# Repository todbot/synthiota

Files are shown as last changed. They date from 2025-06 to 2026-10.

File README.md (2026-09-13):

# synthiota

Pico/Pico2-based board for playing with synthesizers in CircuitPython.

https://github.com/user-attachments/assets/1fe45b23-2a2a-41f4-9afe-203840c703e8

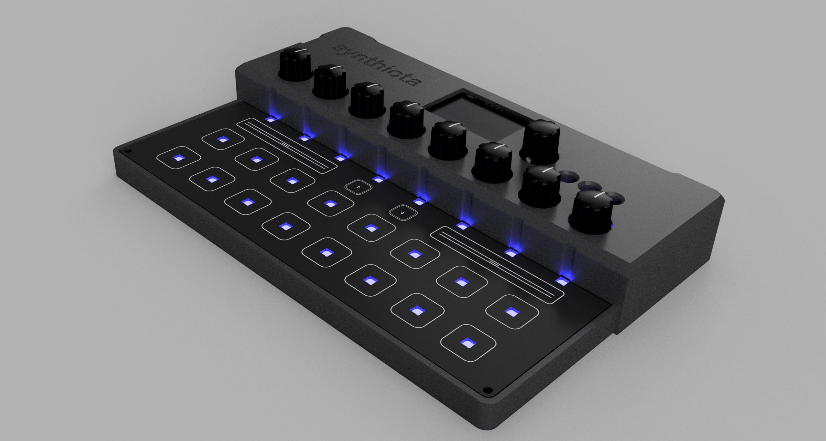
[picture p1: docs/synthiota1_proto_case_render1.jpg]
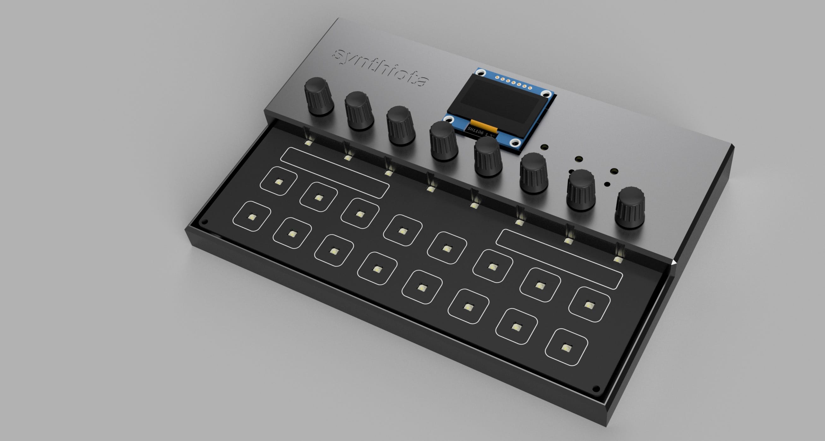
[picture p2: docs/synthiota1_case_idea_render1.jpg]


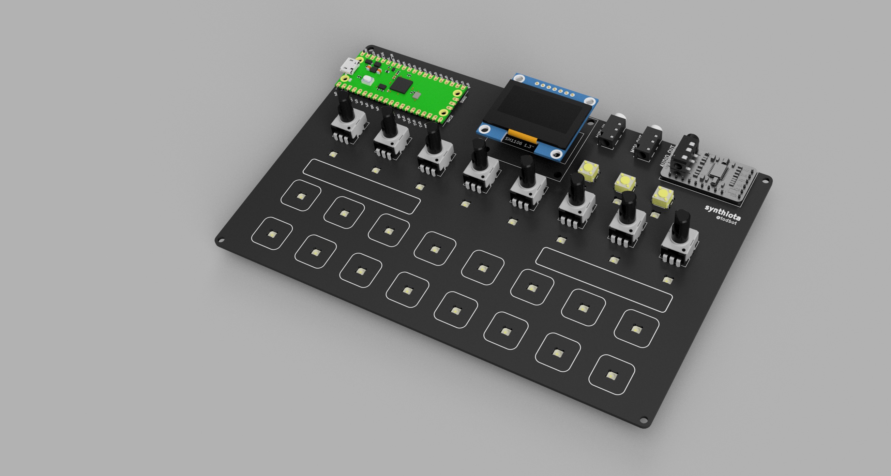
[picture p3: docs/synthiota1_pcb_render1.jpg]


## Video demos:

- "tbish" TB-303 like synth, demo2: https://youtu.be/MjE2wdevc3M
- "tbish" TB-303 like synth, demo1: https://youtu.be/O4a5pk78DVM

# Assembling

The PCBAs come with all SMD parts assembled. The components you will need to supply:

- 1 x Raspberry Pi Pico 2
- 1 x [PCM5102 I2S Stereo DAC](https://amzn.to/4nX4xkD)
- 1 x [SH1106 128x64 1.3" SPI OLED](https://amzn.to/4oUlOeM) 
- 2 x [PJ320A 3.5mm stereo jack](https://amzn.to/4i5F33d)
- 8 x [RK09K 10k vertical potentiometer](https://amzn.to/47XbwEk) (or similar)
- 1 x [EC11 rotary encoder](https://amzn.to/4o1vSSW)

You will also need some headers and header sockets to attach the modules to the PCB.
If using the [enclosure](./enclosure), the top part expects the header arrangement to be:

- Pico: 
  - Standard header pins on Pico  (Pico H sold w/ these pins soldered)
  - [Short socket headers](https://www.adafruit.com/product/5585) for Pico on synthiota board
- OLED display:
  - Standard header pins on OLED display  (usually sold w/ these pins soldered)
  - [Short socket headers](https://www.adafruit.com/product/5585) for OLED display on synthiota board
- PCM5102 I2S DAC
  - Standard header pins on PCM5102 I2S DAC board (usually sold w/ these pins soldered)
  - I2S DAC w/ header pins is soldered directly to the synthiota board, no socket

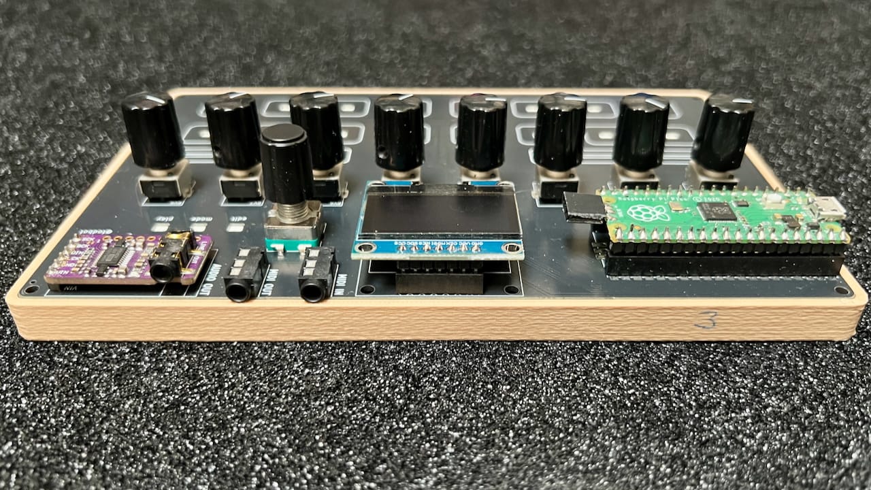
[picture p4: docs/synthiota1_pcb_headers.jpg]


(most links are Amazon affiliate links)

# Pico pins used

CircuitPython naming. See `hwtest/synth_setup_synthiota.py` for how they're used.

Encoder 

* `board.GP28`  - encoder B pin
* `board.GP27`  - encoder A pin

ADC input for pots

* `board.GP26`  - ADC input for pot knobs

I2S DAC 

* `board.GP22`  - I2S DAT pin to PCM5102 DAC
* `board.GP21`  - I2S LCK pin to PCM5102 DAC
* `board.GP20`  - I2S BCK pin to PCM5102 DAC

Encoder switch

* `board.GP19`  - encoder SW pin
 
NeoPixel LEDs
 
* `board.GP18`  - NeoPixel LEDs pin 
 
UART MIDI In/Out
 
* `board.GP17`  - UART RX pin to MIDI input
* `board.GP16`  - UART TX pin to MIDI output

SPI for display

* `board.GP13`  - SPI DC for SH1106 display
* `board.GP12`  - SPI RES for SH1106 display
* `board.GP11`  - SPI MOSI for SH1106 display
* `board.GP10`  - SPI SCK for SH1106 display

Pot mux select

* `board.GP9`   - SEL A pin to 4051 mux for pot knobs
* `board.GP8`   - SEL B pin to 4051 mux for pot knobs
* `board.GP7`   - SEL C pin to 4051 mux for pot knobs

I2C for MPR121 touch sensors

* `board.GP3`   - I2C SCL to MPR121 touch sensors
* `board.GP2`   - I2C SDA to MPR121 touch sensors

Free pins: GP0,GP1, GP4,GP5,GP6, GP14,GP15. Feel free to use for other purposes. 

# Schematics

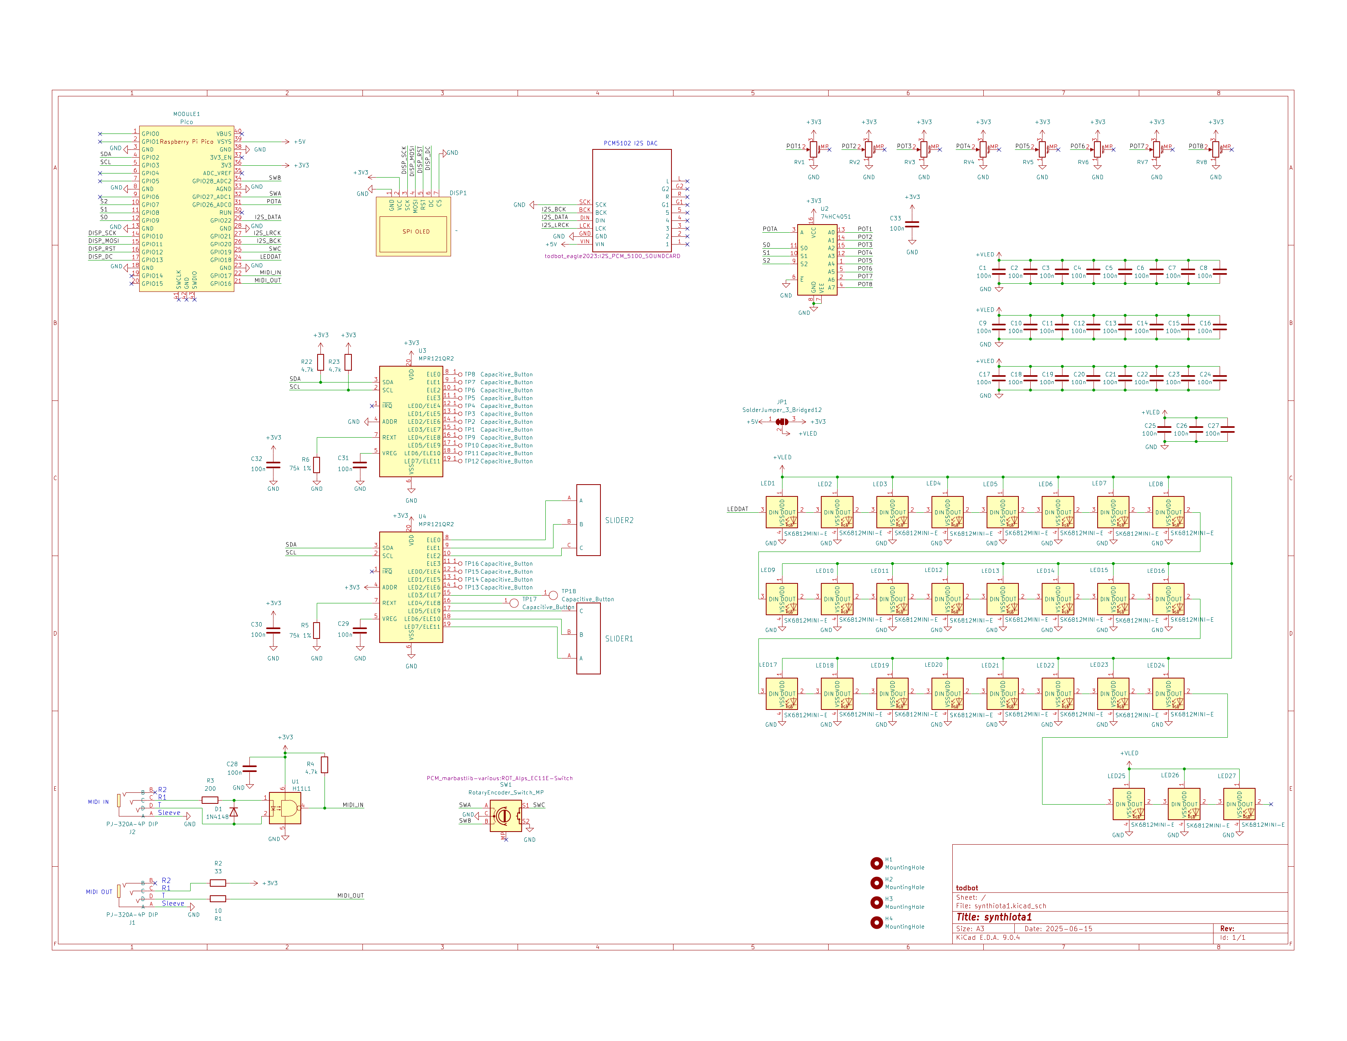
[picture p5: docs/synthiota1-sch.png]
[](./schematics/synthiota1/synthiota1-sch.pdf)

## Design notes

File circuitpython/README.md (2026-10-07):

To install needed third-party libraries, see "requirements.txt".
You can use "circup" to install them with `circup install -r requirements.txt`

For actual applications, see the directories.

- `polysynth/`  - subtractive polysynth on synthtools' SubtractiveSynth
- `wavesynth/`  - wavetable polysynth on synthtools' WavetableSynth
- `tbish/`      - TB-303 inspired mono bass synth
- `tbish2/`     - tbish on synthtools' BasslineSynth
- `synthtest/`  - earlier synth playground

`polysynth/` and `wavesynth/` are ported from the pico_test_synth repo
and run on the `relic_synthiota` hardware library (vendored in `lib/`,
from github.com/relic-se/CircuitPython_Synthiota). Each app folder has
its own README with the control map and copy-to-device steps.

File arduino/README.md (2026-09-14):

# synthiota Arduino sketches

Arduino sketches for the synthiota1 board (RP2040/RP2350), 
built with the [earlephilhower rp2040 core][rp2040-core] and `arduino-cli`.

[rp2040-core]: https://github.com/earlephilhower/arduino-pico

## Sketches

- **hwtest/hwtest1** -- board basic test: I2C scan, dual MPR121
  touch with NeoPixel feedback, 8-pot mux, rotary encoder + switch,
  and a SH1106 SPI OLED status page. See
  `circuitpython/hwtest/synth_setup_synthiota.py` for the pin map this
  is based on.
  
- **hwtest/hwtest2** -- simple monophonic MIDI synth using
  [M16](https://github.com/algomusic/M16), driving the PCM5102 I2S DAC. <br>
  (saw oscillator, fixed lowpass, AR envelope, TRS + USB MIDI)
  
- **hwtest/hwtest3** -- simple monophonic MIDI synth using 
  [Mozzi](https://sensorium.github.io/Mozzi/), similar to hwtest2. <br>
   (saw oscillator, fixed lowpass, AR envelope, TRS + USB MIDI)

## sketch.yaml profiles

Each sketch has a [`sketch.yaml`][sketch-yaml] pinning the exact
platform and library versions it was built against, as `pico` and
`pico2` profiles (`default_profile: pico2`). Profile builds are
self-contained -- `arduino-cli` downloads the pinned platform/library
versions into an isolated store on first use, independent of whatever
is installed globally -- so no separate `core install`/`lib install`
step is needed for these sketches.

Note the Arduino IDE does not read `sketch.yaml`; it only applies to
`arduino-cli` builds. Building from the IDE instead, just open the
`.ino` and pick the board from Tools > Board as usual (see "USB MIDI"
below for hwtest2's extra board option).

[sketch-yaml]: https://arduino.github.io/arduino-cli/latest/sketch-project-file/

## Board FQBNs

| Board | FQBN |
|---|---|
| Raspberry Pi Pico | `rp2040:rp2040:rpipico:usbstack=tinyusb`  |
| Raspberry Pi Pico 2 | `rp2040:rp2040:rpipico2:usbstack=tinyusb` |

## USB Serial and USB MIDI 

Sketches use USB via `Adafruit_TinyUSB` and need the board's
USB Stack set to **Adafruit TinyUSB** instead of the default Pico SDK
stack. If you're using `arduino-cli`, the sketch's `sketch.yaml` profiles
already bake this in, so use  `--profile pico2` or `--profile pico`. 

## Build and upload

From inside a sketch directory (e.g. `arduino/hwtest/hwtest1`):

```sh
# Pico
arduino-cli compile --profile pico .
arduino-cli upload -p /dev/ttyACM0 --profile pico .

# Pico 2 (the default profile)
arduino-cli compile --profile pico2 .
arduino-cli upload -p /dev/ttyACM0 --profile pico2 .

# serial monitor
arduino-cli monitor -p /dev/ttyACM0
```

Adjust `/dev/ttyACM0` to match the board's actual serial port (find it
with `arduino-cli board list`).

To (re)generate a sketch's `sketch.yaml` profiles rather than
hand-tracking library versions, use `arduino-cli`'s `--dump-profile`:

```sh
arduino-cli compile --fqbn rp2040:rp2040:rpipico2 --dump-profile .
```

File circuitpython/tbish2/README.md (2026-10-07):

# tbish2 for synthiota

A TB-303 inspired monophonic bass synth for Synthiota, on `synthtools`'
`BasslineSynth` and `StepSequencer`. The synth engine comes from
[pico_test_synth](https://github.com/todbot/pico_test_synth)'s `tbish2`;
the controls are this repo's [`tbish/`](../tbish/), which is left as is.

Compared to `tbish/`, the library synth adds:

- accent raises resonance (`accent_q`) and cutoff (`accent_cutoff`),
  not just level, and consecutive accents stack
- a real `slide_time`, and slides that TIE: the pitch glides and the
  envelopes carry on, like the original
- a 24 dB/oct filter, drive (RP2350 only) and delay, all as patch fields

## Modes

The encoder steps through three modes, shown bottom right of the screen
and on the mode LEDs:

- **play** .. the 8 pots are the main 303 knobs: cutoff, envmod, resQ,
  decay, accent, wave, drive, delaymix
- **edit** .. the 8 pots set 8 step notes; the screen shows those 8
  steps, with `A` for accent and `S` for slide over each
- **more** .. the 8 pots are the rest of the synth: ampdec, amplevel,
  acctcut, acctQ, slide, drvamt, dtime, dlyfeed

Patterns are 16 steps, shown 8 at a time: `1-8` or `9-16` top right.
Edit mode works on one half, picked with the left slider's middle;
play and more show whichever half is playing.

In play and more, all 8 pots are live and the screen shows the pair
(1-2, 3-4, 5-6, 7-8) of the pot turned last. The pots are scaled
takeover: a turn always moves its parameter, scaled so knob and value
converge without a jump.

## Controls

- encoder turn ............ next / previous mode
- encoder push ............ play / pause; pausing saves to `/tbish2.json`
- step pads, playing ...... transpose the pattern (pad 9 is home)
- step pads, stopped ...... play the synth
- step pads, edit mode .... bottom row: step note <-> rest;
                            top row: normal -> accent -> slide -> both
- up / down buttons ....... transpose up / down an octave
- right slider, left end .. previous pattern
- right slider, right end . next pattern
- hold either right slider end, turn encoder .. scroll patterns
- left slider, middle ..... edit steps 1-8 / 9-16
- hold left slider left end, turn encoder ... bpm
- hold left slider right end, turn encoder .. steps per beat
- pot LEDs ................ current step, if on the shown half
- step LEDs ............... held pads; in edit mode, the pattern
                            (white = note, red = accent, blue = slide)

There's no MIDI in or out yet.

## Patterns

The first five are famous 303 lines, transcribed at
[JonDent's famous 303 bassline patterns](https://djjondent.blogspot.com/2020/04/famous-303-bassline-patterns-page-1.html).
The original BPM is in a comment on each; tbish2 doesn't change tempo
per pattern.

1. Josh Wink - Higher State of Consciousness (134 BPM)
2. Phuture - Acid Tracks (~120 BPM; notes only, no accents or slides)
3. Fast Eddie - Acid Thunder (x0xb0x transcription)
4. DJ Tim & Misjah - Access (134 BPM)
5. New Order - Confusion, Pump Panel Reconstruction (134 BPM)

The rest are tbish's own 8-step patterns, played twice. Patterns saved
in `/tbish2.json` by an 8-step version are ignored, since they no longer
fit; the knobs and bpm still load.

## Running it

From `circuitpython/`:

    circup install -r requirements.txt

Copy to the CIRCUITPY root: `code.py`, `tbish2_ui.py` and `boot.py` from
this folder, plus `lib/relic_synthiota.py`.

`boot.py` makes the filesystem writable from the board's side, so pause
can save the knobs, bpm and patterns. Without it saving fails with a
printed note, and everything else works.

Needs a CircuitPython build with `audiofilters` and `audiodelays` for
the 24 dB filter, drive and delay. Without them it runs on the voice's
own 12 dB filter and says so at boot.

## Notes

- `decay` is the FILTER fall time in seconds; the amp's decay is its own
  knob (`ampdec`) and wants to stay longer, or the sweep is masked. A run
  of slides is one held note on one amp envelope, so `ampdec` also has to
  outlast the whole run, or its later notes fade to nothing.
- `drive` is the distortion's dry/wet mix, as on tbish; how hard it
  distorts is `drvamt` on the more page. RP2350 only.
- `dtime` is milliseconds.
- Audio runs at 44100 Hz, mono: in stereo the delay's buffer is too big
  to allocate. If it glitches, set SAMPLE_RATE to 22050.
- 303 research links: see [`../tbish/README.md`](../tbish/README.md).

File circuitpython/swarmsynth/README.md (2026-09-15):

# swarmsynth for synthiota

A Dewanatron Swarmatron-style drone machine for Synthiota, on
`synthtools`' `SwarmSynth`: eight oscillators on one pitch, fanned apart
by a single "swarm" control and each drifting independently.

The real instrument is monophonic, played from a pitch ribbon, with a
second ribbon and a knob pulling the oscillators from a few cents apart
out to a wide chord of equidistant pitches. This is that, on the pads:
the **bottom row** is eight scale degrees, the **top row** re-aims the
drone by octaves and fifths, and the **right slider** is the span
ribbon. Working the pitch and the span together -- Dewanatron's "taffy
pulling" -- is what the instrument is for.

The 8 pots are one page of 8 parameters, paired on screen so each pair
is one idea. All 8 are live; the screen shows one pair large -- turning
any pot snaps it to that pot's pair (1-2, 3-4, 5-6, 7-8), each param as
`P<n> name` over a big value. The 8 pot LEDs show all 8 values.

The pots are scaled takeover: turning one always moves its parameter,
scaled so the knob and the value converge without a jump, so a nudged
pot never snaps a drone.

## Controls

- bottom pads (1-8) .. the 8 scale degrees (natural minor), one note each
- top pads (9-16) .... transpose the drone: -24 -12 -7 0 +7 +12 +19 +24
                       semitones (pad 12 is home)
- 8 pots ............. 8 params at once; screen shows the last-turned pair
- up / down buttons .. octave down / up (C1 .. C5)
- encoder turn ....... octave down / up (same as the buttons)
- encoder press ...... latch on / off -- the drone keeps sounding after
                       you let go, so both hands are free for the knobs
- left slider ........ nudge filter cutoff (while touched)
- right slider ....... the span ribbon: swarm spread (while touched)
- pot LEDs .......... all 8 param values
- step LEDs ......... held / latched degree, and the chosen transposition
- play LED .......... lit while latched

Bottom-row pads are last-note priority, so rolling a finger across them
glides the drone instead of cutting it. Both sliders move the parameter
itself, so the screen, the pot LED and the pot's takeover all follow
the ribbon.

Page SWARM:  spred drift count wave  freq reso glide rel

- `spred` .. the outermost oscillator's offset, in octaves. 0 is unison,
             0.01 is +/-12 cents, 0.4 is an equidistant cluster spread
             over most of an octave either way.
- `drift` .. depth of each oscillator's slow independent wander. 0 is
             perfect digital tuning, which sounds like a chorus pedal;
             a few thousandths is what makes the swarm breathe.
- `count` .. oscillators per note, 1 to 8.
- `wave` ... SAW SQU TRI SIN ASAW ATRI ASQU SSQU.
- `glide` .. portamento, the pitch ribbon's glissando.

## MIDI

Responds to NOTE ON/OFF on any channel (monophonic), CC 1 (swarm
spread), CC 74 (filter cutoff), CC 120/123 (all notes off). Sends NOTE
ON/OFF for every pitch the pads trigger, on USB and UART -- including
the off that a pitch change implies, since the synth is mono.

A note arriving over MIDI is played as sent, so the top row has nothing
to re-aim while it sounds: the transposition you pick applies to the
next pad press.

## Running it

From `circuitpython/`:

    circup install -r requirements.txt

That installs `synthtools` and the other third-party libraries, plus
the local `lib/` modules (`relic_synthiota.py`, `synthiota_potpage_ui.py`).

Copy to the CIRCUITPY root: the contents of this folder, plus
`lib/synthtools/` and the `lib/*.py` modules.

`relic_synthiota.py` originates at
github.com/relic-se/CircuitPython_Synthiota

## Notes

- `wave` and `count` apply at the NEXT note-on: the waveform is baked
  into each `synthio.Note` and the count decides how many Notes a press
  builds. Re-press a pad to hear either one change. `spred` and `drift`
  are each one write into a shared block and move a held drone live,
  which is the whole point of the engine.
- Turning `count` down under a held drone re-tunes it: the fan
  coefficients are shared, so the sounding oscillators re-space to the
  new count even though they keep their number.
- `rel` stops at 2.0s on purpose. Mono at 8 oscillators is 8 Notes,
  16 while a steal overlaps the releasing swarm with the new one,
  against synthio's 24. A longer tail plus a fast roll across pads
  stacks a third releasing swarm and the oldest gets dropped.
- `SwarmSynth.FILT_F_MAX` is set from `sample_rate * 0.45` before the
  synth is constructed: the Nyquist clamp is baked into the block graph
  at build time.
- The mixer voice runs at 0.8 because each Note is amplitude
  `velocity / 127 / swarm_count`: detuned oscillators beat, so their
  peaks do periodically line up, and the level is made back up here.
- Audio runs at 44100 Hz. If it glitches, set SAMPLE_RATE to 22050.

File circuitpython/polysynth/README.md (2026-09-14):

# polysynth for synthiota

A playable two-oscillator subtractive polysynth for Synthiota, on
`synthtools`' `SubtractiveSynth`. Ported from 
[pico_test_synth](https://github.com/todbot/pico_test_synth)'s 
`synthtools_polysynth`.

The 16 step pads are a chromatic keyboard. The 8 pots edit 8 parameters
at once; the encoder turns pages (16 parameters over 2 pages, OSC/AMP
and FILT/MOD). All 8 pots on a page are live, but the screen shows one
pair large -- turning any pot snaps it to that pot's pair (1-2, 3-4,
5-6, 7-8), each param as `P<n> name` over a big value. The 8 pot LEDs
show all 8 values on the page. USB and TRS MIDI both play the synth;
pad presses echo out both.

The pots are scaled takeover: turning one always moves its parameter,
scaled so the knob and the value converge without a jump, so a page
turn or a nudged pot never snaps a sound.

## Controls

- step pads .......... chromatic keyboard (16 notes)
- 8 pots ............. 8 params at once; screen shows the last-turned pair
- encoder turn ....... previous / next page
- up / down buttons .. octave down / up (C1 .. C5)
- left slider ........ nudge filter cutoff (while touched)
- right slider ....... vibrato depth (while touched)
- pot LEDs .......... all 8 param values on this page
- step LEDs ......... currently held notes

## MIDI

Responds to NOTE ON/OFF on any channel, CC 1 (vibrato depth), CC 74
(filter cutoff), CC 120/123 (all notes off). Sends NOTE ON/OFF for pad
presses on USB and UART.

## Running it

From `circuitpython/`:

    circup install -r requirements.txt

That installs `synthtools` and the other third-party libraries, plus
the local `lib/` modules (`relic_synthiota.py`, `synthiota_potpage_ui.py`).

Copy to the CIRCUITPY root: the contents of this folder, plus
`lib/synthtools/` and the `lib/*.py` modules.

`relic_synthiota.py` originates at
github.com/relic-se/CircuitPython_Synthiota

## Notes

- `SubtractiveSynth.FILT_F_MAX` is set from `sample_rate * 0.45` before
  the synth is constructed: the Nyquist clamp is baked into the block
  graph at build time.
- Audio runs at 44100 Hz. If it glitches, set SAMPLE_RATE to 22050.
- `detune` below 1.0005 snaps to exactly 1.0, which is the single-
  oscillator path (one Note per key). Any real detune spends two Notes
  per key.

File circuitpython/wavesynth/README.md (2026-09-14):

# wavesynth for synthiota

A wavetable polysynth for Synthiota, on `synthtools`' `WavetableSynth`.
Ported from pico_test_synth's `wavesynth`.

`wpos` moves within the loaded wavetable and morphs sounding notes
live; `wsel` picks which `.WAV` in `wavetables/`. Two LFOs: `lamt` /
`lrate` over the filter cutoff, and `wlfo` / `wrate` sweeping `wpos` up
toward `wlfo` (a ceiling at or below `wpos` means no sweep).

The 16 step pads are an 8x2 **scale keyboard** (`lib/harmony.py`): the
bottom row is the 8 scale degrees, one note each; the top row plays a
diatonic chord on the last bottom pad pressed. Scale and key are on the
KEY/MOD page.

The 8 pots edit 8 parameters at once and the encoder turns pages (24
parameters over 3 pages: WAVE, ENV/FILT, KEY/MOD). All 8 pots on a page
are live, but the screen shows one pair large -- turning any pot snaps
it to that pot's pair (1-2, 3-4, 5-6, 7-8), each param as `P<n> name`
over a big value. The 8 pot LEDs show all 8 values on the page.

The pots are scaled takeover: turning one always moves its parameter,
scaled so the knob and the value converge without a jump, so a page
turn or a patch load never snaps a sound.

Nine patches are defined in code (`default_patches()`); there is no
disk save.

## Controls

- bottom pads (1-8) ...... the 8 scale degrees, one note each
- top pads (9-16) ........ chord on the last bottom pad: root, oct, 5th,
                           triad, 7th, 9th, sus, spread (all diatonic)
- 8 pots ................. 8 params at once; screen shows the last-turned pair
- encoder turn ........... previous / next page
- encoder HOLD + bottom pad  load patch 1..8
- up / down buttons ...... octave down / up
- left slider ............ nudge filter cutoff (while touched)
- right slider ........... wavetable position (while touched)
- pot LEDs .............. all 8 param values on this page
- step LEDs ............. currently held pads

Page WAVE:    freq reso wpos wsel wlfo wrate atk rel
Page ENV/FILT: fatk frel famt ftype lamt lrate vdep vol
Page KEY/MOD: scale key wshp w1x wvel vrate pamt ptime
  (wshp/w1x/wvel = wave-LFO shape / one-shot / velocity depth)

## MIDI

Responds to NOTE ON/OFF on any channel (played chromatically, not
snapped to the scale), CC 1 (wavetable position), CC 74 (filter
cutoff), CC 120/123 (all notes off). Sends NOTE ON/OFF for every note a
pad triggers, on USB and UART.

## Running it

From `circuitpython/`:

    circup install -r requirements.txt

That installs `synthtools` and the other third-party libraries, plus
the local `lib/` modules (`relic_synthiota.py`, `synthiota_potpage_ui.py`,
`harmony.py`).

Copy to the CIRCUITPY root: the contents of this folder including
`wavetables/`, plus `lib/synthtools/` and the `lib/*.py` modules.
Then run `dot_clean -m /Volumes/CIRCUITPY`.

`harmony.py` (scales + chords) is standalone for now, headed for
`synthtools.harmony`.

`relic_synthiota.py` originates at
github.com/relic-se/CircuitPython_Synthiota.

## Notes

- Audio runs at 44100 Hz. Set `SAMPLE_RATE` to 22050 if it glitches.
- `WavetableSynth.FILT_F_MAX` is set from `sample_rate * 0.45` before
  the synth is constructed (Nyquist clamp, baked in at build time).
- `wpos` and `wlfo` are re-ranged whenever `wsel` loads a different
  file: the wavetables here hold 64 waves each and a fixed ceiling would
  hide most of every table.
- The wave LFO only advances when `synth.update()` runs; the main loop
  calls it every pass, a cheap no-op while `wlfo <= wpos`.
- macOS drops `._`-prefixed AppleDouble files into `wavetables/` on a
  FAT drive; `wave_files()` skips them, but `dot_clean -m /Volumes/CIRCUITPY`
  after copying is still worth it.

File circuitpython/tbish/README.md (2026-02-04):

# TBish synth

A TB-303 inspired monophonic bass synth.

Video demo on synthiota1: https://www.youtube.com/watch?v=O4a5pk78DVM

Video demo of pico_test_synth running tbish: https://www.youtube.com/watch?v=1AflpXbEIno

Current code in here is a technology demo. 
There's no way to edit patterns or play it via MIDI. 

notes: 

- [Analysis of Diode Ladder Filter in TB303](https://www.timstinchcombe.co.uk/index.php?pge=diode)
- [Devilfish mods of TB303, increasing range of CutOff & EnvMod pots](https://www.firstpr.com.au/rwi/dfish/303-mods/)
- [Investigating unique aspects of the 303 sound, particular the filter envelope](https://www.firstpr.com.au/rwi/dfish/303-unique.html)
- [kvr forum discussion of 303 ladder filter, with commens by u-he](https://www.kvraudio.com/forum/viewtopic.php?t=346155)
- [modwigger forum on 303 circuit modeling](https://modwiggler.com/forum/viewtopic.php?t=289244)
- [TeeBeeFilter.h - C model of 303/Moog ladder filter](https://github.com/RobinSchmidt/Open303/blob/main/Source/DSPCode/rosic_TeeBeeFilter.h)
- [x0xb0x filter block diagram](https://www.ladyada.net/wiki/x0x/voltagecontrolledfilter)
- [Emulate a 303 with Ableton's Operator plugin](https://beatproduction.net/how-to-emulate-a-tb-303-with-abletons-operator/)
- [Reddit post of recreating 303 sound in Eurorack](https://www.reddit.com/r/modular/comments/bvoqff/making_a_eurorack_tb303/)

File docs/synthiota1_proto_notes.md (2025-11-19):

# Synthiota1 Proto 15 Jun 2025 Notes

## Overall

- All the parts of the board seem to work!

## PCB

- Sliders suck, they're too small
  - Can somewhat fix it in software by increasing the charge current, 
   `mpr121s[1]._write_register_byte(adafruit_mpr121.MPR121_CONFIG1, 0x20)  # default, 2*16uA charge current? `
   - solution: make sliders taller? ditch sliders entirely? 

- Layout too cramped vertically, towards the pot LED area

- Missing Play/Pause button? 
  - new 1 Sep 2025 version adds another touch button for this

## Software

- Maybe model after the Bass Station II

    - patch parameters:
      - osc1 octave
      - osc1 mod env depth
      - osc1 lfo depth
      - osc1 waveform
      - amp env attack
      - amp env release
      - amp env sustain
      - amp env decay
      
      - filt type
      - filt freq
      - filt resonance
      - filt env attack
      - filt env release
      - filt env sustain
      - filt env decay
      
      - delay
      - overdrive
      - reverb
      - detune

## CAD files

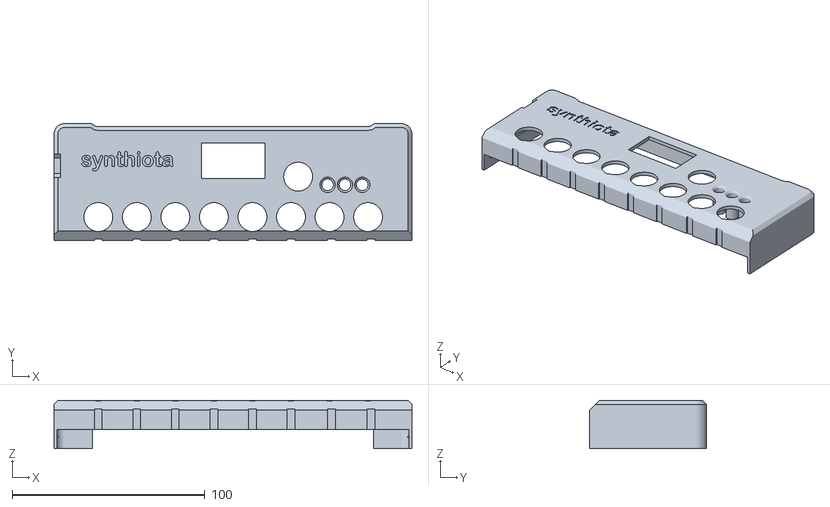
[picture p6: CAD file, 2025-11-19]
enclosure/synthiota_proto_case_top.stl
185.8 x 60.7 x 25.0

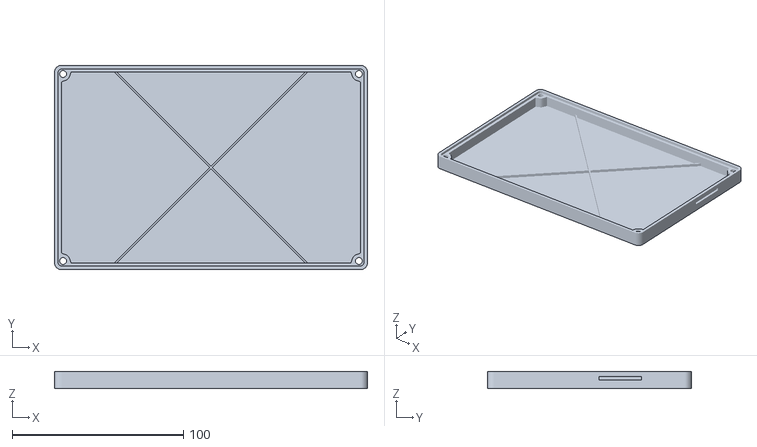
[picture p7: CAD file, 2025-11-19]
enclosure/synthiota_proto_case_bot.stl
182.8 x 119.3 x 10.00

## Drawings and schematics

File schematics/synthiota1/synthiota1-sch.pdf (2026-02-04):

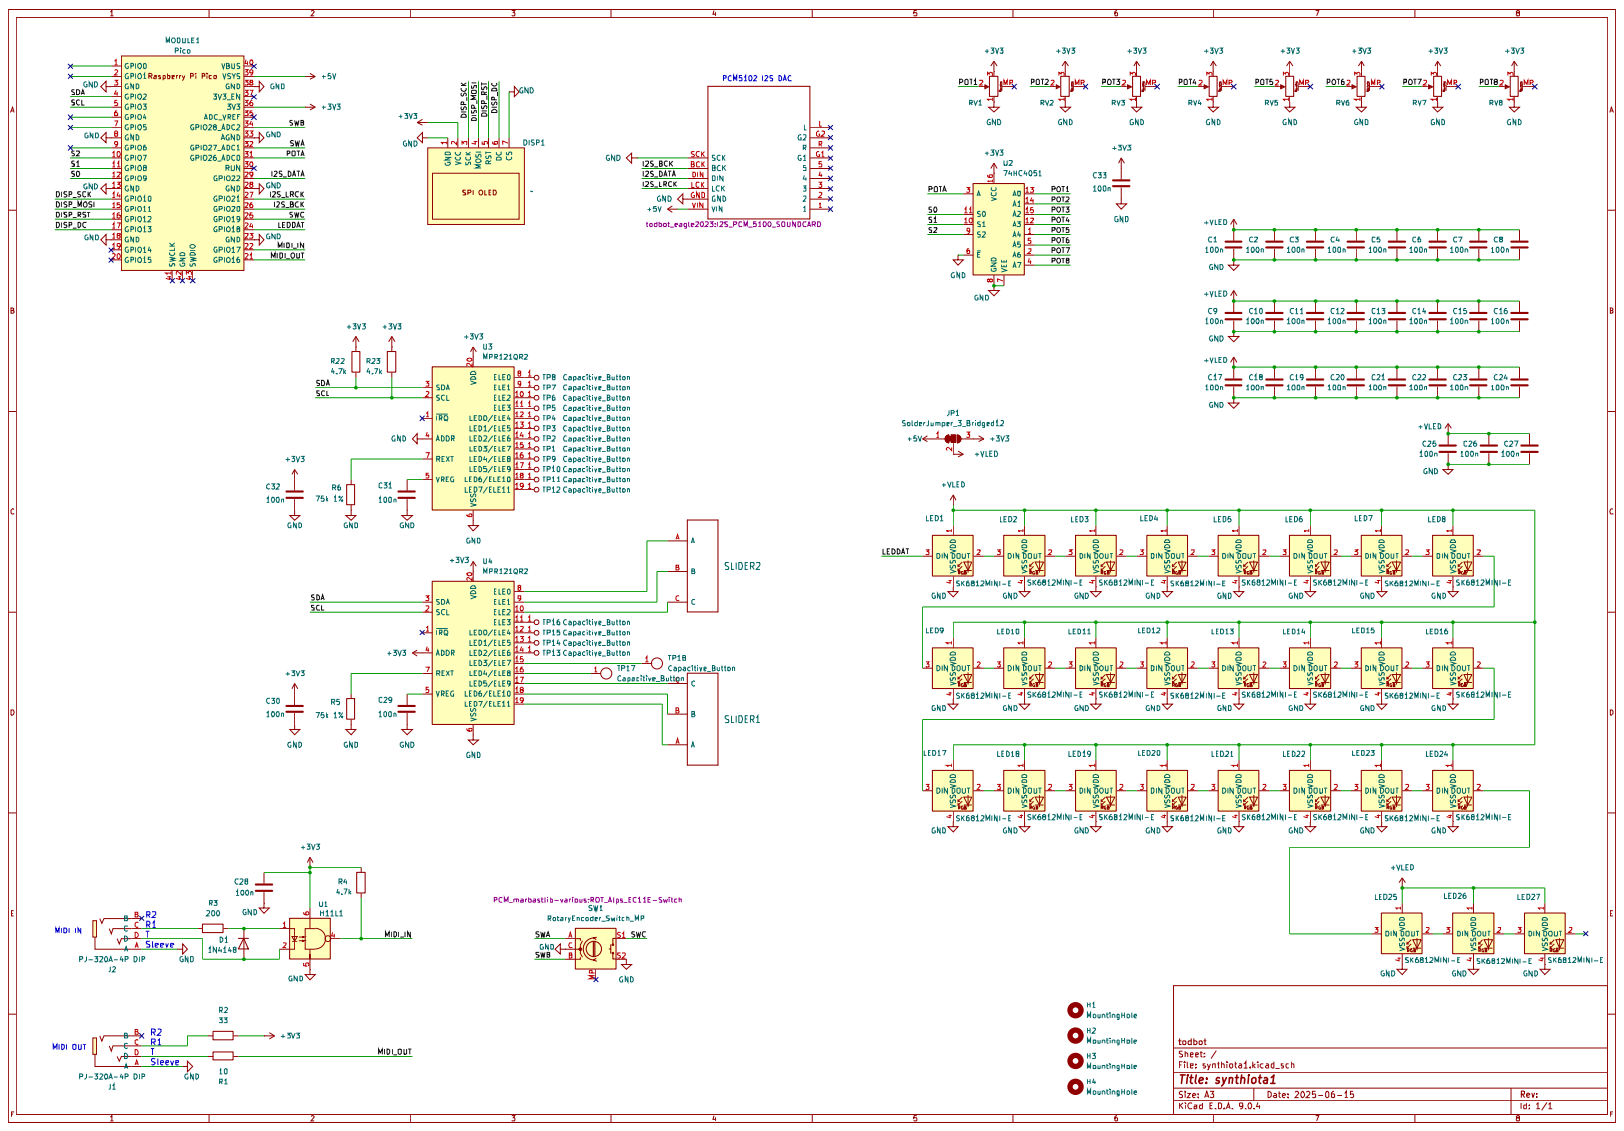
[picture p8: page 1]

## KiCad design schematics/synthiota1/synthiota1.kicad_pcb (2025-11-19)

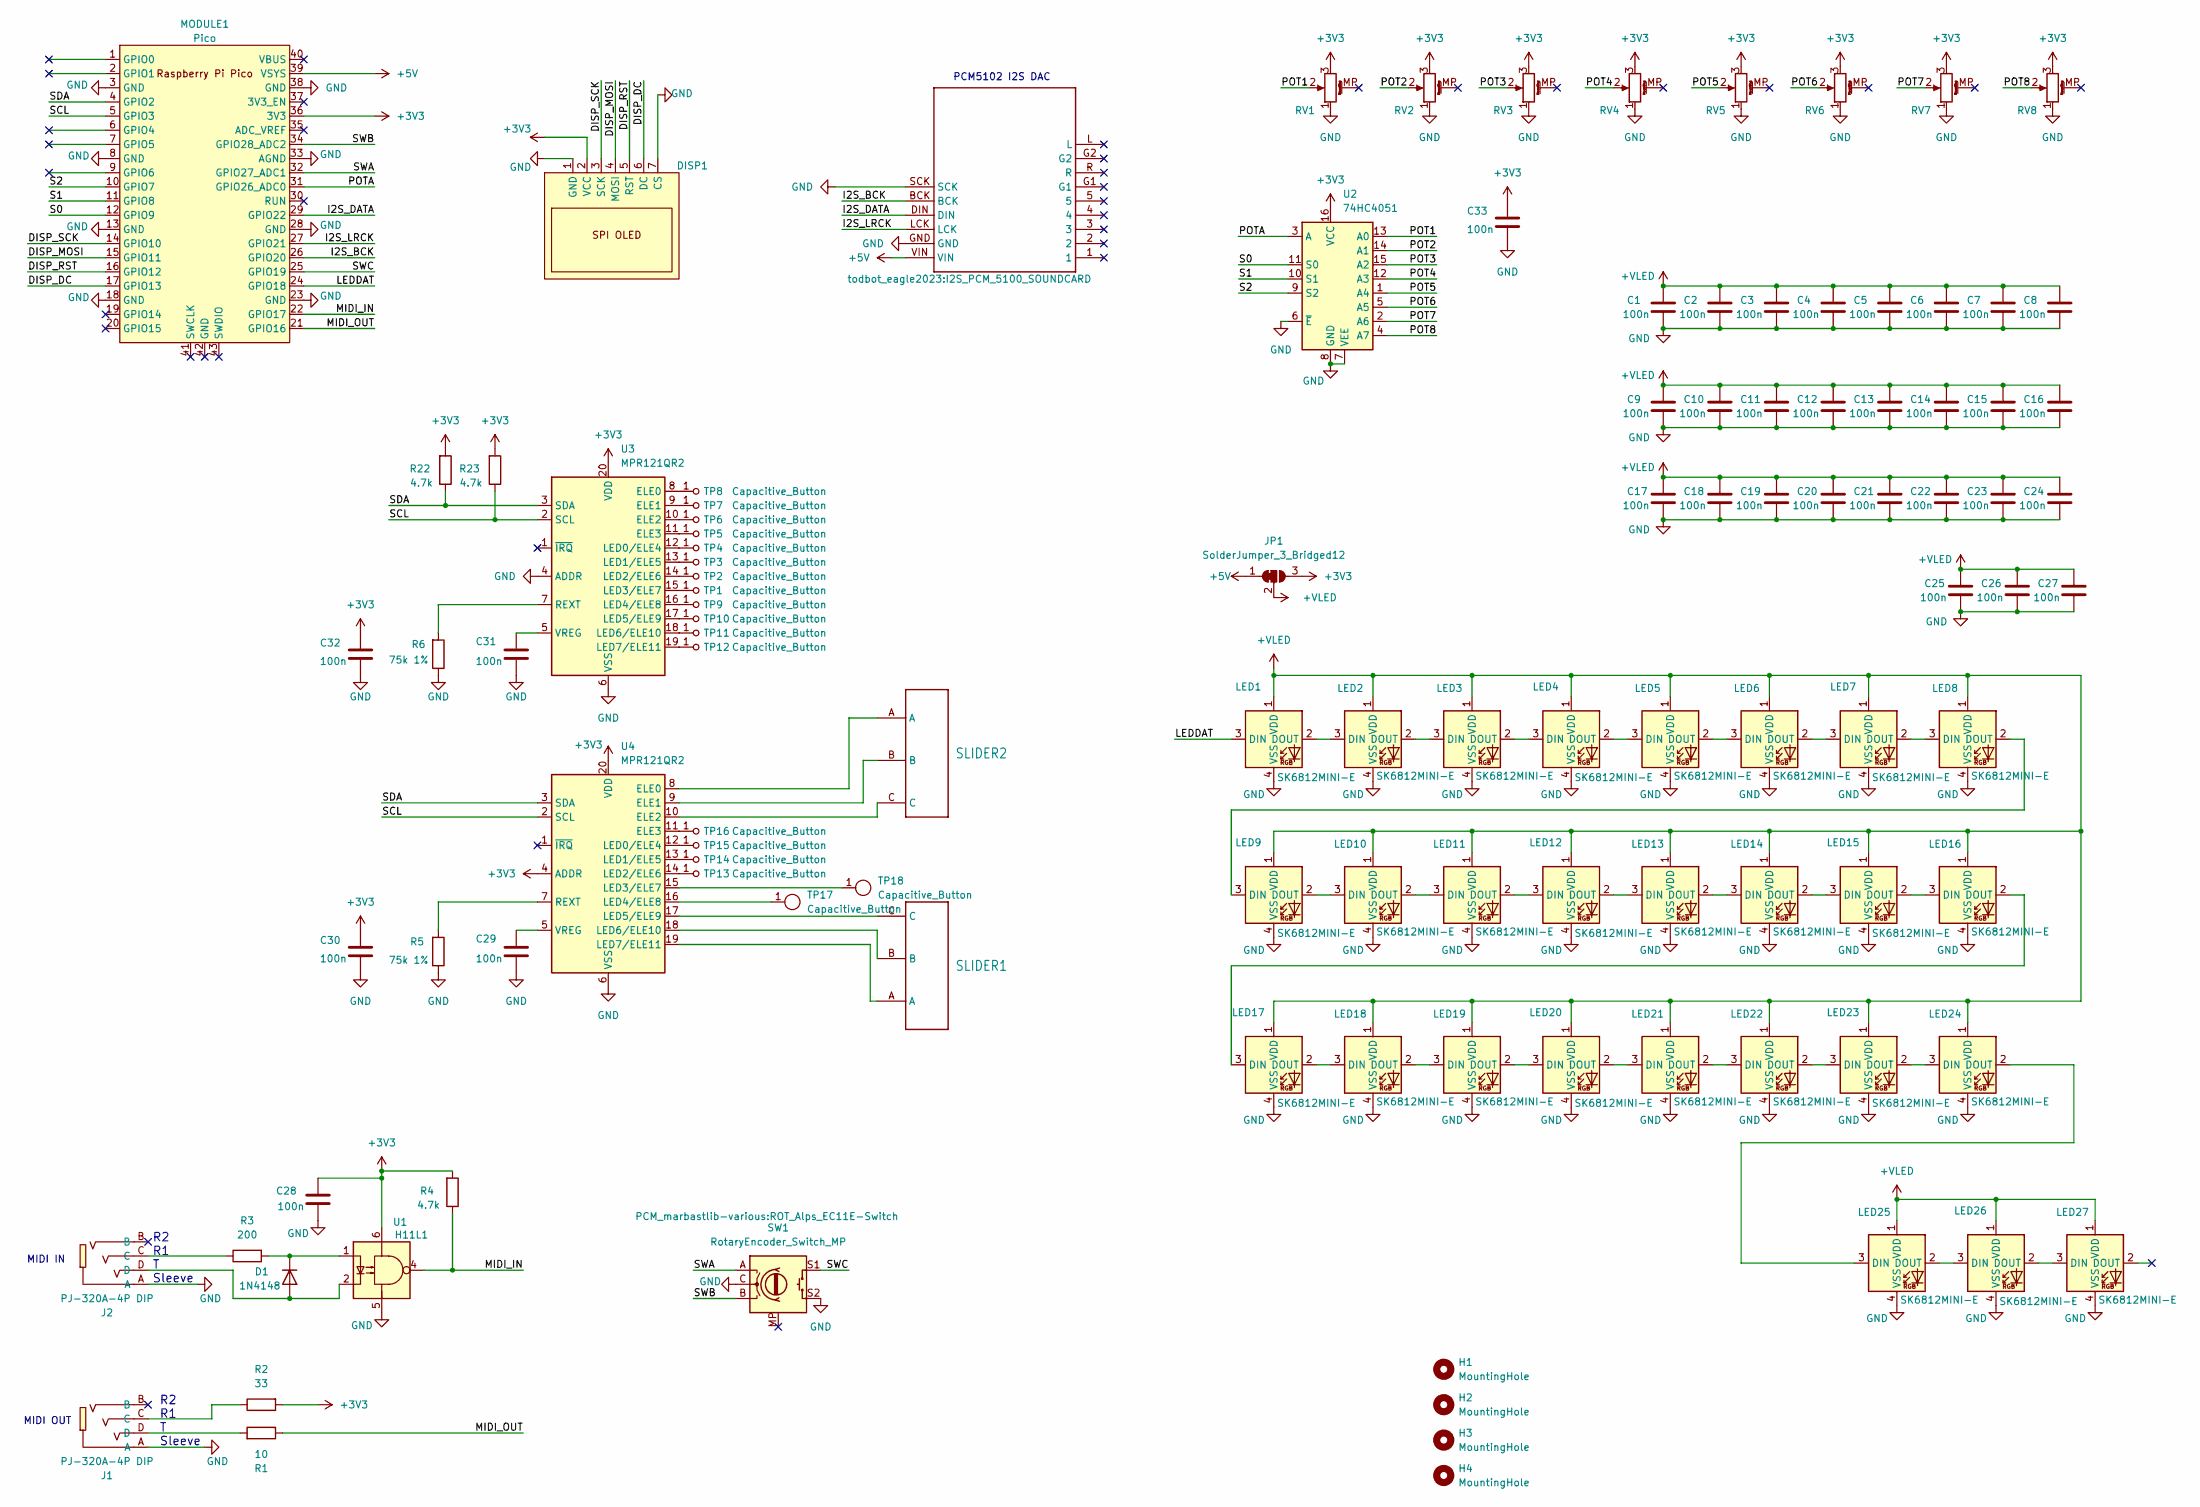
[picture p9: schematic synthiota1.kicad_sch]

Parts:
C1, C2, C3, C4, C5, C6, C7, C8, C9, C10, C11, C12, C13, C14, C15, C16, C17, C18, C19, C20, C21, C22, C23, C24, C25, C26, C27, C28, C29, C30, C31, C32, C33: 100n; C_0603_1608Metric; LCSC Part C1590
D1: 1N4148; D_SOD-123; LCSC Part C81598
DISP1: DISPLAY-OLED-128X64-1.3IN
H1, H2, H3, H4: MountingHole; MountingHole_2.7mm_M2.5
J1, J2: PJ-320A-4P DIP; AUDIO-TH_PJ-320A-4P-DIP; LCSC Part C18185602
JP1: SolderJumper_3_Bridged12; SolderJumper-3_P1.3mm_Bridged12_RoundedPad1.0x1.5mm
LED1, LED2, LED3, LED4, LED5, LED6, LED7, LED8, LED9, LED10, LED11, LED12, LED13, LED14, LED15, LED16, LED17, LED18, LED19, LED20, LED21, LED22, LED23, LED24, LED25, LED26, LED27: SK6812MINI-E; LED_6028R; LCSC Part C5149201
MODULE1: Pico; RPi_Pico_SMD_TH
MODULE2: I2S_PCM_5100_SOUNDCARD
R1: 10; R_0603_1608Metric; LCSC Part C22859
R2: 33; R_0603_1608Metric; LCSC Part C23140
R3: 200; R_0603_1608Metric; LCSC Part C8218
R4, R22, R23: 4.7k; R_0603_1608Metric; LCSC Part C23162
R5, R6: 75k 1%; R_0603_1608Metric; LCSC Part C23242
RV1, RV2, RV3, RV4, RV5, RV6, RV7, RV8: R_Potentiometer_MountingPin; Potentiometer_Alps_RK09K_Single_Vertical
SLIDER1, SLIDER2: TouchSlider3_50x8mm_ti
SW1: RotaryEncoder_Switch_MP; ROT_Alps_EC11E-Switch
TP1, TP2, TP3, TP4, TP5, TP6, TP7, TP8, TP9, TP10, TP11, TP12, TP13, TP14, TP15, TP16: Capacitive_Button; TOUCHPAD_KEY_0.5IN_LEDHOLE
TP17, TP18: Capacitive_Button; Pad-CapTouch-8mm-roundrect
U1: H11L1; SMD-6_L7.3-W6.5-P2.54-LS10.2-BL; LCSC C78589
U2: 74HC4051; SOIC-16_L9.9-W3.9-P1.27-LS6.0-BL; LCSC Part C2943297
U3, U4: MPR121QR2; UQFN-20_3x3mm_P0.4mm; LCSC Part C91322

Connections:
+3V3: C28.1, C30.1, C32.1, C33.1, DISP1.2 (VCC), JP1.3 (B), MODULE1.36 (3V3), R2.2, R4.2, R22.2, R23.2, RV1.3, RV2.3, RV3.3, RV4.3, RV5.3, RV6.3, RV7.3, RV8.3, U1.6, U2.16 (VCC), U3.20 (VDD), U4.4 (ADDR), U4.20 (VDD)
+5V: JP1.1 (A), MODULE1.39 (VSYS), MODULE2.VIN
+VLED: C1.1, C2.1, C3.1, C4.1, C5.1, C6.1, C7.1, C8.1, C9.1, C10.1, C11.1, C12.1, C13.1, C14.1, C15.1, C16.1, C17.1, C18.1, C19.1, C20.1, C21.1, C22.1, C23.1, C24.1, C25.1, C26.1, C27.1, JP1.2 (C), LED1.1 (VDD), LED2.1 (VDD), LED3.1 (VDD), LED4.1 (VDD), LED5.1 (VDD), LED6.1 (VDD), LED7.1 (VDD), LED8.1 (VDD), LED9.1 (VDD), LED10.1 (VDD), LED11.1 (VDD), LED12.1 (VDD), LED13.1 (VDD), LED14.1 (VDD), LED15.1 (VDD), LED16.1 (VDD), LED17.1 (VDD), LED18.1 (VDD), LED19.1 (VDD), LED20.1 (VDD), LED21.1 (VDD), LED22.1 (VDD), LED23.1 (VDD), LED24.1 (VDD), LED25.1 (VDD), LED26.1 (VDD), LED27.1 (VDD)
/DISP_DC: DISP1.6 (DC), MODULE1.17 (GPIO13)
/DISP_MOSI: DISP1.4 (MOSI), MODULE1.15 (GPIO11)
/DISP_RST: DISP1.5 (RST), MODULE1.16 (GPIO12)
/DISP_SCK: DISP1.3 (SCK), MODULE1.14 (GPIO10)
/I2S_BCK: MODULE1.26 (GPIO20), MODULE2.BCK
/I2S_DATA: MODULE1.29 (GPIO22), MODULE2.DIN
/I2S_LRCK: MODULE1.27 (GPIO21), MODULE2.LCK
/LEDDAT: LED1.3 (DIN), MODULE1.24 (GPIO18)
/MIDI_IN: MODULE1.22 (GPIO17), R4.1, U1.4
/MIDI_OUT: MODULE1.21 (GPIO16), R1.1
/POT1: RV1.2, U2.13 (A0)
/POT2: RV2.2, U2.14 (A1)
/POT3: RV3.2, U2.15 (A2)
/POT4: RV4.2, U2.12 (A3)
/POT5: RV5.2, U2.1 (A4)
/POT6: RV6.2, U2.5 (A5)
/POT7: RV7.2, U2.2 (A6)
/POT8: RV8.2, U2.4 (A7)
/POTA: MODULE1.31 (GPIO26_ADC0), U2.3 (A)
/S0: MODULE1.12 (GPIO9), U2.11 (S0)
/S1: MODULE1.11 (GPIO8), U2.10 (S1)
/S2: MODULE1.10 (GPIO7), U2.9 (S2)
/SCL: MODULE1.5 (GPIO3), R23.1, U3.2 (SCL), U4.2 (SCL)
/SDA: MODULE1.4 (GPIO2), R22.1, U3.3 (SDA), U4.3 (SDA)
/SWA: MODULE1.32 (GPIO27_ADC1), SW1.A
/SWB: MODULE1.34 (GPIO28_ADC2), SW1.B
/SWC: MODULE1.25 (GPIO19), SW1.S1
GND: C1.2, C2.2, C3.2, C4.2, C5.2, C6.2, C7.2, C8.2, C9.2, C10.2, C11.2, C12.2, C13.2, C14.2, C15.2, C16.2, C17.2, C18.2, C19.2, C20.2, C21.2, C22.2, C23.2, C24.2, C25.2, C26.2, C27.2, C28.2, C29.2, C30.2, C31.2, C32.2, C33.2, DISP1.1 (GND), DISP1.7 (CS), J1.A, J2.A, LED1.4 (VSS), LED2.4 (VSS), LED3.4 (VSS), LED4.4 (VSS), LED5.4 (VSS), LED6.4 (VSS), LED7.4 (VSS), LED8.4 (VSS), LED9.4 (VSS), LED10.4 (VSS), LED11.4 (VSS), LED12.4 (VSS), LED13.4 (VSS), LED14.4 (VSS), LED15.4 (VSS), LED16.4 (VSS), LED17.4 (VSS), LED18.4 (VSS), LED19.4 (VSS), LED20.4 (VSS), LED21.4 (VSS), LED22.4 (VSS), LED23.4 (VSS), LED24.4 (VSS), LED25.4 (VSS), LED26.4 (VSS), LED27.4 (VSS), MODULE1.3 (GND), MODULE1.8 (GND), MODULE1.13 (GND), MODULE1.18 (GND), MODULE1.23 (GND), MODULE1.28 (GND), MODULE1.33 (AGND), MODULE1.38 (GND), MODULE2.GND, MODULE2.SCK, R5.1, R6.1, RV1.1, RV2.1, RV3.1, RV4.1, RV5.1, RV6.1, RV7.1, RV8.1, SW1.C, SW1.S2, U1.5, U2.6 (~E), U2.7 (VEE), U2.8 (GND), U3.4 (ADDR), U3.6 (VSS), U4.6 (VSS)
unnamed: D1.2 (A), J2.D, U1.2
unnamed: D1.1 (K), R3.2, U1.1
unnamed: J1.C, R2.1
unnamed: J1.D, R1.2
unnamed: J2.C, R3.1
unnamed: LED1.2 (DOUT), LED2.3 (DIN)
unnamed: LED2.2 (DOUT), LED3.3 (DIN)
unnamed: LED3.2 (DOUT), LED4.3 (DIN)
unnamed: LED4.2 (DOUT), LED5.3 (DIN)
unnamed: LED5.2 (DOUT), LED6.3 (DIN)
unnamed: LED6.2 (DOUT), LED7.3 (DIN)
unnamed: LED7.2 (DOUT), LED8.3 (DIN)
unnamed: LED8.2 (DOUT), LED9.3 (DIN)
unnamed: LED9.2 (DOUT), LED10.3 (DIN)
unnamed: LED10.2 (DOUT), LED11.3 (DIN)
unnamed: LED11.2 (DOUT), LED12.3 (DIN)
unnamed: LED12.2 (DOUT), LED13.3 (DIN)
unnamed: LED13.2 (DOUT), LED14.3 (DIN)
unnamed: LED14.2 (DOUT), LED15.3 (DIN)
unnamed: LED15.2 (DOUT), LED16.3 (DIN)
unnamed: LED16.2 (DOUT), LED17.3 (DIN)
unnamed: LED17.2 (DOUT), LED18.3 (DIN)
unnamed: LED18.2 (DOUT), LED19.3 (DIN)
unnamed: LED19.2 (DOUT), LED20.3 (DIN)
unnamed: LED20.2 (DOUT), LED21.3 (DIN)
unnamed: LED21.2 (DOUT), LED22.3 (DIN)
unnamed: LED22.2 (DOUT), LED23.3 (DIN)
unnamed: LED23.2 (DOUT), LED24.3 (DIN)
unnamed: LED24.2 (DOUT), LED25.3 (DIN)
unnamed: LED25.2 (DOUT), LED26.3 (DIN)
unnamed: LED26.2 (DOUT), LED27.3 (DIN)
unnamed: TP1.1 (A), U3.15 (LED3/ELE7)
unnamed: TP2.1 (A), U3.14 (LED2/ELE6)
unnamed: TP3.1 (A), U3.13 (LED1/ELE5)
unnamed: TP4.1 (A), U3.12 (LED0/ELE4)
unnamed: TP5.1 (A), U3.11 (ELE3)
unnamed: TP6.1 (A), U3.10 (ELE2)
unnamed: TP7.1 (A), U3.9 (ELE1)
unnamed: TP8.1 (A), U3.8 (ELE0)
unnamed: TP9.1 (A), U3.16 (LED4/ELE8)
unnamed: TP10.1 (A), U3.17 (LED5/ELE9)
unnamed: TP11.1 (A), U3.18 (LED6/ELE10)
unnamed: TP12.1 (A), U3.19 (LED7/ELE11)
unnamed: TP13.1 (A), U4.14 (LED2/ELE6)
unnamed: TP14.1 (A), U4.13 (LED1/ELE5)
unnamed: TP15.1 (A), U4.12 (LED0/ELE4)
unnamed: TP16.1 (A), U4.11 (ELE3)
unnamed: TP17.1 (A), U4.16 (LED4/ELE8)
unnamed: TP18.1 (A), U4.15 (LED3/ELE7)
unnamed: R6.2, U3.7 (REXT)
unnamed: C31.1, U3.5 (VREG)
unnamed: SLIDER2.A, U4.8 (ELE0)
unnamed: SLIDER2.B, U4.9 (ELE1)
unnamed: SLIDER2.C, U4.10 (ELE2)
unnamed: SLIDER1.C, U4.17 (LED5/ELE9)
unnamed: SLIDER1.B, U4.18 (LED6/ELE10)
unnamed: SLIDER1.A, U4.19 (LED7/ELE11)
unnamed: R5.2, U4.7 (REXT)
unnamed: C29.1, U4.5 (VREG)

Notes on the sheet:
MIDI IN
PCM5102 I2S DAC
R2 R1 T Sleeve
MIDI OUT

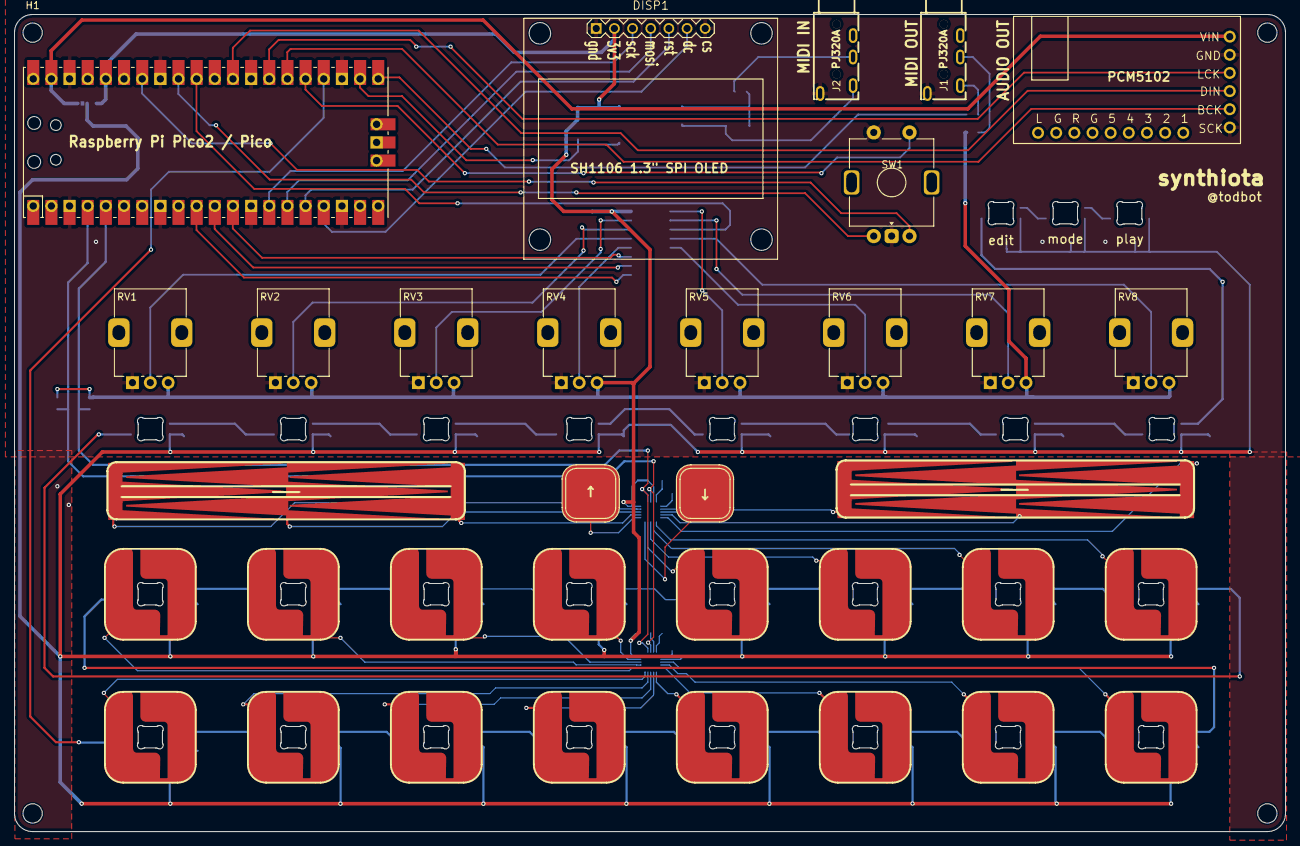
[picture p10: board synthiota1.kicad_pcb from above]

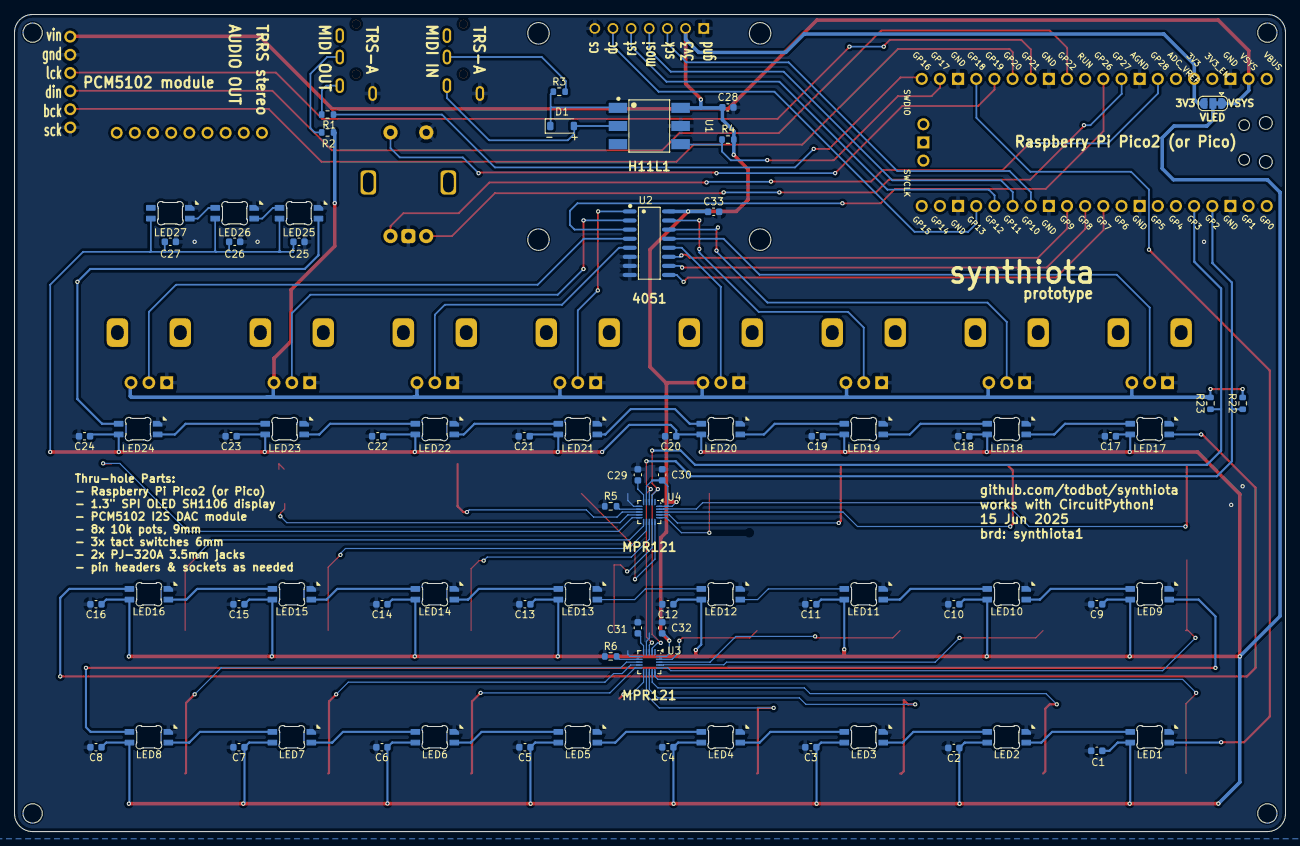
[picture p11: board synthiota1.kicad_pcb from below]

Board: 2 copper layers, 177.8 x 114.3 mm, 112 parts (74 on the bottom side), 90 nets.

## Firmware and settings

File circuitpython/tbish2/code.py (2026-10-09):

# SPDX-FileCopyrightText: Copyright (c) 2026 Tod Kurt
# SPDX-License-Identifier: MIT
#
# tbish2 -- a TB-303-like acid bassline on Synthiota,
#           using synthtools' BasslineSynth
#
# Ported from pico_test_synth's tbish2, with the controls of this repo's
# tbish/: the encoder steps through three modes, "play" (pots edit the
# main 303 knobs), "edit" (pots set 8 step notes, pads toggle rests,
# accents and slides) and "more" (pots edit the rest of the synth).
# Patterns are 16 steps; the screen, pads and pots show 8 at a time.
#
#   encoder turn .............. next / previous mode
#   encoder push .............. play / pause (pause saves to /tbish2.json)
#   step pads, playing ........ transpose the pattern
#   step pads, stopped ........ play the synth
#   up / down ................. octave up / down
#   right slider, left / right end ... previous / next pattern
#   left slider, middle .............. edit steps 1-8 / 9-16
#   hold right slider end + encoder .. scroll patterns
#   hold left slider, left end + encoder ... bpm
#   hold left slider, right end + encoder .. steps per beat

import microcontroller
microcontroller.cpu.frequency = 200_000_000

import json
import os
import time
import synthio

import relic_synthiota
from synthtools import BasslineSynth, Patch
from synthtools.paramset import Param, ParamSet
from synthtools.step_sequencer import StepSequencer
from tbish2_ui import TBish2UI

#SAMPLE_RATE = 44100  # set to 22050 here if audio glitches
SAMPLE_RATE = 22050

# distortion is too expensive on an rp2040
IS_RP2350 = "rp2350" in os.uname()[0]

UI_INTERVAL = 0.05
PARAMS_FILE = "/tbish2.json"
PAD_VELOCITY = 80  # below BasslineSynth.accent_velocity, or every pad accents
GATE = 0.75  # traditional 303 gate length, as a fraction of a step
# >1 so the note is still held when the next step ties to it. Margin over
# 1.0 is how late a loop pass can be before the tie silently breaks.
TIE_GATE = 1.5
SPB_ALLOWED = (1, 2, 4, 8, 16)

MODE_PLAY, MODE_EDIT, MODE_MORE = 0, 1, 2

# touch ids, see relic_synthiota's pad defs
LSLIDE_A = 23  # left slider, left end
LSLIDE_B = 22  # left slider, middle
LSLIDE_C = 21  # left slider, right end
RSLIDE_A = 12  # right slider, left end
RSLIDE_C = 14  # right slider, right end

# waveform names, from _builders in synthtools/waves.py
WAVES = ("SAW", "SQU", "ASAW", "ASQU", "TRI", "SIN")

# --- the patterns --------------------------------------------------------
# notes (0 = rest), velocities (>100 = accent), slides (1 = slide into this
# step from the last; on a 303 the flag is on the step BEFORE the slide)
# Famous ones from https://djjondent.blogspot.com/2020/04/famous-303-bassline-patterns-page-1.html
# fmt: off
SEQS = [
    # New Order - Confusion (Pump Panel Reconstruction, 1995), 134 BPM
    [[ 43,  43,  43,  43,   0,  31,  43,   0,    46,   0,  34,  34,  34,  46,   0,  34],
     [ 80,  80,  80,  80,  80,  80,  80,  80,    80,  80,  80,  80,  80,  80,  80,  80],
     [  0,   1,   1,   0,   0,   0,   0,   0,     0,   0,   0,   1,   0,   0,   0,   0]],

    # Phuture - Acid Tracks (1987), ~120 BPM. Only the 8 notes are
    # published; accents and slides were tweaked live, so none here.
    [[ 35,  35,  36,  48,  36,  39,  39,  48,    35,  35,  36,  48,  36,  39,  39,  48],
     [ 80,  80,  80,  80,  80,  80,  80,  80,    80,  80,  80,  80,  80,  80,  80,  80],
     [  0,   0,   0,   0,   0,   0,   0,   0,     0,   0,   0,   0,   0,   0,   0,   0]],

    # Fast Eddie - Acid Thunder (1988), BPM unknown; x0xb0x transcription
    [[ 39,  39,  42,  40,  40,  40,  43,  43,    43,  48,  48,  47,  38,  38,  39,  39],
     [ 80,  80, 127,  80,  80,  80, 127,  80,    80,  80,  80,  80,  80,  80,  80,  80],
     [  0,   1,   0,   0,   1,   1,   0,   1,     1,   0,   1,   0,   0,   1,   0,   1]],

    # Josh Wink - Higher State of Consciousness (1995), 134 BPM
    [[ 43,  55,  43,  43,  43,  43,  47,  43,    47,  43,  43,  47,  43,  43,  43,  47],
     [127, 127, 127, 127, 127, 127, 127, 127,   127, 127, 127, 127, 127, 127, 127, 127],
     [  0,   1,   0,   1,   1,   0,   0,   0,     0,   0,   1,   0,   0,   1,   1,   0]],

    # DJ Tim & Misjah - Access (1995), 134 BPM
    [[ 45,   0,  45,  57,  45,  45,  45,   0,    45,  45,  57,  45,   0,  45,  45,   0],
     [ 80,  80,  80,  80, 127,  80,  80,  80,    80,  80,  80,  80,  80,  80,  80,  80],
     [  0,   0,   0,   0,   0,   0,   0,   0,     0,   0,   0,   0,   0,   0,   0,   0]],

    # tbish's own 8-step patterns, played twice
    [[24,  36, 48, 36,  48, 48+7, 36, 48] * 2,
     [127, 80, 80, 80,  127,  80, 80, 80] * 2,
     [0,    0,  0,  0,   0,   1,  0,  1] * 2],

    [[36,   0,   0,  0,  24,    0,   0,  0] * 2,
     [127, 80,  80, 80,  127 , 80, 127, 80] * 2,
     [0,    1,   1,  0,   0,    1,   0,  1] * 2],

    [[36,  48, 36, 48,  36,  48, 36, 48] * 2,
     [127, 80, 80, 80,  127, 80, 80, 80] * 2,
     [0,    0,  1,  1,   0,   1,  0,  1] * 2],

    [[36, 36, 34, 36,  48, 48, 36, 48] * 2,
     [127, 80, 127, 80,  127, 80, 127, 80] * 2,
     [0,    0,  0,  0,   0,   0,  0,  0] * 2],

    [[36,  24,  36, 48,  36, 0, 36, 0] * 2,
     [127, 80, 80, 80,  127, 80, 127, 80] * 2,
     [0,    1,  1,  0,   0,   0,  0,  0] * 2],
]
# fmt: on
STEP_COUNT = len(SEQS[0][0])
PAGE = 8  # steps shown and edited at once

# --- the patch -----------------------------------------------------------
# `decay` (the FILTER fall) must be shorter than the gate and the amp decay
# longer, or the envmod sweep is masked and every step is just a pluck.
# fmt: off
patch = Patch(
    name="tbish2",
    synth_type="bassline",
    wave="ASAW",
    filt_type="LPF",
    filt_f=2345,
    filt_q=1.8,
    envmod=0.5,
    decay=0.3,
    # long decay: a run of slides is ONE note, so it must outlast the run
    amp_env=[0.001, 1.0, 0.0, 0.02],
    fenv_curve=2,
    accent=0.5,
    accent_cutoff=4000,
    accent_q=0.8,
    amp_level=0.75,      # un-accented level, so accents have room
    slide_time=0.09,
    fx_filter_stages=1,  # one extra stage makes the voice's 12 dB/oct 24
    # STRUCTURAL: nothing can turn these on later
    fx_distortion_on=IS_RP2350,
    fx_echo_on=True,
    fx_drive=0.6,
    fx_drive_mix=0.0,
    fx_delay_ms=330.0,
    fx_delay_mix=0.0,
    fx_delay_decay=0.3,
)
# fmt: on

# mono: stereo doubles every fx buffer, and the Echo's alone (1 s at
# 44.1 kHz) is then too big to allocate
s = relic_synthiota.Synthiota(sample_rate=SAMPLE_RATE, channel_count=1)
s.display.auto_refresh = False
s.leds.auto_write = False
s.leds.brightness = 0.3

sio = synthio.Synthesizer(sample_rate=s.sample_rate, channel_count=s.channel_count)
BasslineSynth.FILT_F_MAX = s.sample_rate * 0.45  # SUBCLASS, before constructing
bass = BasslineSynth(sio, patch)

# Without bass.output the fx chain is bypassed and the synth sounds thin.
OUT_LPF_F = 8000  # tames the top of the aliased saw; can't remove what folds below it
try:
    import audiofilters

    # 4th-order Butterworth: two stages at these Qs
    out_lpf = audiofilters.Filter(
        filter=(synthio.Biquad(synthio.FilterMode.LOW_PASS, OUT_LPF_F, Q=0.541),
                synthio.Biquad(synthio.FilterMode.LOW_PASS, OUT_LPF_F, Q=1.307)),
        sample_rate=s.sample_rate, channel_count=s.channel_count,
        buffer_size=BasslineSynth.FX_BUFFER_SIZE)
    out_lpf.play(bass.output)
    s.mixer.voice[0].play(out_lpf)
except ImportError:
    print("no audiofilters/audiodelays in this build: 12 dB/oct, no drive, no delay")
    s.mixer.voice[0].play(sio)

# --- the 16 synth parameters: page 0 is "play" mode, page 1 "more" --------
# fmt: off
PARAMS = [
    Param("cutoff",   patch.filt_f,        100,  4000,  "%4d",   "filt_f"),
    Param("envmod",   patch.envmod,        0.0,  1.0,   "%.2f",  "envmod"),
    # 4.0, not 6.0: an accent adds up to accent_q on top
    Param("resQ",     patch.filt_q,        0.6,  8.0,   "%.2f",  "filt_q"),
    # a 16th's gate is ~90 ms, so a longer fall is never heard
    Param("decay",    patch.decay,         0.01, 2.0,  "%.2f",  "decay"),
    Param("accent",   patch.accent,        0.0,  1.0,   "%.2f",  "accent"),
    Param("wave",     WAVES.index(patch.wave), 0, len(WAVES) - 1, "%.0f", None),
    # the mix, as tbish's Drive knob was: an amount alone is never heard
    Param("drive",    patch.fx_drive_mix,  0.0,  1.0,   "%.2f",  "fx_drive_mix"),
    Param("delaymix", patch.fx_delay_mix,  0.0,  0.5,   "%.2f",  "fx_delay_mix"),

    Param("ampdec",   patch.amp_env[1],    0.02, 3.0,   "%.2f",  "decay_time"),
    Param("amplevel", patch.amp_level,     0.1,  1.0,   "%.2f",  "amp_level"),
    Param("acctcut",  patch.accent_cutoff, 0,    6000,  "%4d",   "accent_cutoff"),
    Param("acctQ",    patch.accent_q,      0.0,  2.0,   "%.2f",  "accent_q"),
    Param("slide",    patch.slide_time,    0.01, 0.25,  "%.2f",  "slide_time"),
    Param("drvamt",   patch.fx_drive,      0.0,  1.0,   "%.2f",  "fx_drive"),
    Param("dtime",    patch.fx_delay_ms,   0,    1000,  "%4d",   "fx_delay_ms"),
    Param("dlyfeed",  patch.fx_delay_decay, 0.0, 0.9,   "%.2f",  "fx_delay_decay"),
]
# fmt: on

# knob_deadband well above a muxed synthiota pot's ~0.004 rest jitter
param_set = ParamSet(PARAMS, num_knobs=8, knob_mode=ParamSet.KNOB_SCALE,
                     knob_deadband=0.012)

# edit mode: one pot per step note, one knobset per half
NOTE_PARAMS = [Param("step%d" % (i + 1), 36, 24, 72, "%d") for i in range(STEP_COUNT)]
note_set = ParamSet(NOTE_PARAMS, num_knobs=8, knob_mode=ParamSet.KNOB_SCALE,
                    knob_deadband=0.012)


def apply_param(p):
    # round(), not int(): a full-scale knob sits a hair under vmax
    if p.name == "wave":
        bass.wave = WAVES[round(p.val)]
    else:
        p.apply_to_obj(bass)


def param_text(p):
    if p.name == "wave":
        return WAVES[round(p.val)]
    return p.fmt % p.val


# --- the sequencer -------------------------------------------------------
seqs = [[list(row) for row in seq] for seq in SEQS]
seq_num = 0
bpm = 120
spb = 4
transpose = 0
transpose_oct = 0


def on_step(note, vel, gate, on):
    if not on:  # a rest; `note` is already transposed, so it is not 0
        # a live edit can rest the step a held tie was waiting on
        bass.all_notes_off()
        return
    # .i is still this step's index, it advances after on_func
    slide = seqs[seq_num][2][sequencer.i]
    bass.note_on_step(note, slide=bool(slide), accent=vel > 100, velocity=vel)


def off_step(note, vel, gate, on):
    if on:
        bass.note_off(note)


sequencer = StepSequencer(STEP_COUNT, spb, on_func=on_step, off_func=off_step)


def load_steps():
    """Copy the current pattern into the sequencer. Call on any edit."""
    notes, vels, slides = seqs[seq_num]
    for i in range(STEP_COUNT):
        nxt = (i + 1) % STEP_COUNT
        # a tie onto a rest would leave this note with no note_off
        tie = notes[i] and notes[nxt] and slides[nxt]
        sequencer.steps[i] = [notes[i], vels[i], TIE_GATE if tie else GATE, notes[i] > 0]


def set_seq(n):
    global seq_num
    seq_num = n
    for p, note in zip(NOTE_PARAMS, seqs[n][0]):
        if note:
            p.val = note
    load_steps()


def set_tempo():
    sequencer.steps_per_beat = spb
    sequencer.bpm = bpm  # derived from steps_per_beat, so set after it


def save():
    state = {
        "params": {p.name: p.val for p in PARAMS},
        "bpm": bpm, "spb": spb, "seq": seq_num, "seqs": seqs,
    }
    try:
        with open(PARAMS_FILE, "w") as f:
            json.dump(state, f)
    except OSError:
        print("could not write", PARAMS_FILE, "-- needs boot.py's remount")


def load():
    """Replace the defaults with whatever save() last wrote, if anything."""
    global bpm, spb, seq_num, seqs
    try:
        with open(PARAMS_FILE) as f:
            state = json.load(f)
    except (OSError, ValueError):
        return
    # by name, so a file saved from an older PARAMS list can't smear
    for p in PARAMS:
        v = state["params"].get(p.name)
        if v is not None and p.vmin <= v <= p.vmax:
            p.val = v
    if 30 <= state.get("bpm", 0) <= 240:
        bpm = state["bpm"]
    if state.get("spb") in SPB_ALLOWED:
        spb = state["spb"]
    loaded = state.get("seqs")
    if loaded and all(len(seq) == 3 and all(len(row) == STEP_COUNT for row in seq)
                      for seq in loaded):
        seqs = loaded
    seq_num = min(state.get("seq", 0), len(seqs) - 1)


try:
    load()
except (AttributeError, KeyError, TypeError):
    # e.g. pico_test_synth's tbish2 saves a different shape to the same name
    print("ignoring", PARAMS_FILE, "-- not a tbish2 save")

for _p in PARAMS:
    if _p.objattr and _p.objattr not in bass._PARAMS:
        raise ValueError("no such synth parameter: '%s'" % _p.objattr)
    apply_param(_p)
set_tempo()
set_seq(seq_num)

print("tbish2: encoder turns modes, push to play/pause")

# --- the UI --------------------------------------------------------------
ui = TBish2UI(s.display, PAGE, param_text)
mode = MODE_PLAY
edit_half = 0  # which PAGE of steps edit mode works on
pat_scrolled = False  # encoder turned while a pattern pad is held
pair = 0  # which pot pair (0..3) the screen shows; last pot turned wins
enc_last = s.encoder.position
last_ui = 0.0
last_steps = s.touched_steps
last_touched = s.touched
pad_notes = {}  # step pad -> note it is playing, while stopped


def set_mode(m):
    global mode, pair
    mode = m
    pair = 0
    if mode == MODE_EDIT:
        note_set.knob_pos_last = None
    else:
        param_set.idx = 0 if mode == MODE_PLAY else 1
        param_set.knob_pos_last = None  # re-adopt pots, no phantom move
    ui.show_mode(mode)


def set_edit_half(h):
    global edit_half
    edit_half = h
    note_set.idx = h
    note_set.knob_pos_last = None


def set_transpose():
    sequencer.transpose = transpose + transpose_oct * 12


def step_pad_pressed(n):
    global transpose
    notes, vels, slides = seqs[seq_num]
    if mode == MODE_EDIT:
        i = edit_half * PAGE + n % PAGE
        if n < PAGE:  # bottom row: note <-> rest
            notes[i] = 0 if notes[i] else round(NOTE_PARAMS[i].val)
        else:  # top row: normal -> accent -> slide -> both
            state = (vels[i] > 100) + 2 * bool(slides[i])
            state = (state + 1) % 4
            vels[i] = 127 if state & 1 else 80
            slides[i] = state >> 1
        load_steps()
    elif sequencer.playing:
        transpose = n - 8
        set_transpose()
    else:
        note = 36 + n + transpose_oct * 12
        pad_notes[n] = note
        bass.note_on(note, PAD_VELOCITY)


def step_pad_released(n):
    note = pad_notes.pop(n, None)
    if note is not None:
        bass.note_off(note)


def check_pads():
    """Returns True if any pad changed, so the UI pass can skip a refresh."""
    global last_steps, last_touched, pat_scrolled
    steps = s.touched_steps
    touched = s.touched
    changed = steps != last_steps or touched != last_touched
    for n in range(16):
        if steps[n] != last_steps[n]:
            if steps[n]:
                step_pad_pressed(n)
            else:
                step_pad_released(n)
    # on release, so a hold that scrolled with the encoder doesn't also step
    for pad, d in ((RSLIDE_A, -1), (RSLIDE_C, 1)):
        if touched[pad] and not last_touched[pad]:
            pat_scrolled = False
        elif last_touched[pad] and not touched[pad] and not pat_scrolled:
            set_seq((seq_num + d) % len(seqs))
    if touched[LSLIDE_B] and not last_touched[LSLIDE_B]:
        set_edit_half(1 - edit_half)
    last_steps = steps
    last_touched = touched
    return changed


def check_buttons():
    global transpose_oct
    if s.encoder_button.pressed:
        if sequencer.playing:
            sequencer.stop()
            save()
        else:
            sequencer.start()
    d = 1 if s.up_button.pressed else -1 if s.down_button.pressed else 0
    if d:
        transpose_oct = min(max(transpose_oct + d, -2), 3)
        set_transpose()


def check_encoder():
    global enc_last, bpm, spb, pat_scrolled
    pos = s.encoder.position
    d = enc_last - pos  # this encoder counts down going clockwise
    enc_last = pos
    if not d:
        return
    if last_touched[LSLIDE_A]:
        bpm = min(max(bpm + d, 30), 240)
        set_tempo()
    elif last_touched[LSLIDE_C]:
        i = SPB_ALLOWED.index(spb) + d
        spb = SPB_ALLOWED[min(max(i, 0), len(SPB_ALLOWED) - 1)]
        set_tempo()
    elif last_touched[RSLIDE_A] or last_touched[RSLIDE_C]:
        pat_scrolled = True
        set_seq((seq_num + d) % len(seqs))
    else:
        set_mode((mode + d) % 3)


def update_pots():
    global pair
    knobs = s.pots
    if mode == MODE_EDIT:
        notes = seqs[seq_num][0]
        first = edit_half * PAGE
        before = [p.val for p in NOTE_PARAMS]
        note_set.update_knobs(knobs)
        moved = False
        for i in range(first, first + PAGE):
            p = NOTE_PARAMS[i]
            if p.val != before[i]:
                notes[i] = round(p.val)
                moved = True
        if moved:
            load_steps()
        return
    first = param_set.idx * param_set.nknobs
    page = PARAMS[first : first + param_set.nknobs]
    before = [p.val for p in page]
    param_set.update_knobs(knobs)
    for i, p in enumerate(page):
        if p.val != before[i]:
            apply_param(p)
            pair = i // 2
    ui.show_params(page[pair * 2], page[pair * 2 + 1])


def update_leds(half, step):
    first = half * PAGE
    notes, vels, slides = seqs[seq_num]
    leds = [0] * 16
    if mode == MODE_EDIT:
        for i in range(PAGE):
            leds[i] = 0x333333 if notes[first + i] else 0
            accent = 0x330000 if vels[first + i] > 100 else 0
            slide = 0x000033 if slides[first + i] else 0
            leds[i + PAGE] = accent | slide
    else:
        for n in range(16):
            if last_steps[n]:
                leds[n] = 0x00AAFF
    s.step_leds = leds
    pots = [0] * PAGE
    if step is not None and step // PAGE == half:
        pots[step % PAGE] = 0x333333
    s.pot_leds = pots
    s.edit_led = 0x333333 if mode == MODE_EDIT else 0
    s.mode_led = 0x333333 if mode == MODE_MORE else 0
    beat = step is not None and step % spb == 0
    s.play_led = 0x333333 if beat or not sequencer.playing else 0
    s.leds.show()


def update_ui():
    update_pots()
    step = None
    if sequencer.playing:
        step = (sequencer.i - 1) % STEP_COUNT  # .i has already advanced
    # edit mode stays on the half being edited; otherwise follow the playhead
    if mode == MODE_EDIT:
        half = edit_half
    else:
        half = 0 if step is None else step // PAGE
    first = half * PAGE
    on_page = step is not None and step // PAGE == half
    ui.show_beat(step % PAGE if on_page else None)
    ui.show_half(half)
    ui.show_status(bpm, spb, sequencer.transpose, seq_num)
    ui.show_seq(*(row[first : first + PAGE] for row in seqs[seq_num]))
    update_leds(half, step)


set_mode(MODE_PLAY)

while True:
    sequencer.update()
    s.update()
    pads_changed = check_pads()
    check_buttons()
    check_encoder()

    now = time.monotonic()
    if now - last_ui > UI_INTERVAL:
        last_ui = now
        update_ui()
        # not on a pass that just built a voice
        if ui.dirty and not pads_changed:
            s.display.refresh()
            ui.dirty = False

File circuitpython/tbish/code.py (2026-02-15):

# SPDX-FileCopyrightText: Copyright (c) 2025 Tod Kurt
# SPDX-License-Identifier: MIT
"""
`code.py`
================================================================================

This is the main code.py for a TB-like synth.

The UI has two "pages': Play and Edit.


8 Feb 2026 - @todbot / Tod Kurt

"""
# this reduces some of per-step latency from 10ms down to 6ms, sigh
import microcontroller
microcontroller.cpu.frequency = 200_000_000

import time, random, gc
from micropython import const
import ulab.numpy as np
import rainbowio
import synthio
from synthiota_synth_setup import (display, leds, uart, mpr121s,
                                   update_pots, encoder, encoder_sw, get_touch_events,
                                   mixer, Pads)

from mapped_pot_controller import MappedPotController, Parameter

from tbish_synth import TBishSynth, waves
from tbish_sequencer import TBishSequencer
from tbish_ui import TBishUI


bpm = 120
steps_per_beat = 4   # 4 = 16th note, 2 = 8th note, 1 = quarter note

steps_per_beat_allowed = [1, 2, 4, 8, 16]

tbsynth = TBishSynth(mixer.sample_rate, mixer.channel_count)
mixer.voice[0].play(tbsynth.audio_out)

seqs = [
    [[24,  36, 48, 36,  48, 48+7, 36, 48],    # notes: midi notenum
     [127, 80, 80, 80,  127,  80, 80, 80],    # vels: 100+ = accent, 
     [0,    0,  0,  0,   0,   1,  0,  1]],    # slide/rest: 0 = normal, 1 = slide
        
    [[36,   0,   0,  0,  24,    0,   0,  0],  # notes, 0 = rest 
     [127, 80,  80, 80,  127 , 80, 127, 80],  
     [0,    1,   1,  0,   0,    1,   0,  1]], # slides: 1 = slide
    
    [[36,  48, 36, 48,  36,  48, 36, 48],  # notes, 0 = rest
     [127, 80, 80, 80,  127, 80, 80, 80],  # vels 100+ = accent
     [0,    0,  1,  1,   0,   1,  0,  1]], # slides: 1 = slide
    
    [[36, 36, 34, 36,  48, 48, 36, 48],      # notes, 0 = rest
     [127, 80, 127, 80,  127, 80, 127, 80],  # vels 100+ = accent
     [0,    0,  0,  0,   0,   0,  0,  0]],   # slides: 1 = slide
    
    [[36,  24,  36, 48,  36, 0, 36, 0],     # notes, 0 = rest
     [127, 80, 80, 80,  127, 80, 127, 80],  # vels 100+ = accent
     [0,    1,  1,  0,   0,   0,  0,  0]],  # slides: 1 = slide
]

myconfig = [
    [
        Parameter(100, 5000, "Freq", callback=tbsynth.set_cutoff),
        Parameter(0.0, 1.0, "EnvMod", callback=tbsynth.set_envmod),
        Parameter(0.5, 4.0, "ResQ", callback=tbsynth.set_resonance),
        Parameter(0.0, 1.0, "Decay", callback=tbsynth.set_decay),
        Parameter(0.0, 1.0, "Accent", callback=tbsynth.set_accent),
        Parameter(0,   3,   "Wave", options=["SQU", "SAW", "SW2", "SW3"], callback=tbsynth.set_wavenum),
        Parameter(0.0, 1.0, "Drive", callback=tbsynth.set_drive_mix),
        Parameter(0.0, 1.0, "Delay", callback=tbsynth.set_delay_mix),
    ],
    [
        Parameter(24, 72, 'step0'),
        Parameter(24, 72, 'step1'),
        Parameter(24, 72, 'step2'),
        Parameter(24, 72, 'step3'),
        Parameter(24, 72, 'step4'),
        Parameter(24, 72, 'step5'),
        Parameter(24, 72, 'step6'),
        Parameter(24, 72, 'step7'),
    ],   
    [
        Parameter(30, 180, "BPM"),   # some ideas, not implemented
        Parameter(0, len(seqs)-1, "SeqNum"),
        Parameter(-2, +3, "Transpose"),
        Parameter(0.0, 1.0, "DelaylTime"),
        Parameter(0.0, 1.0, "DriveGain"),
        
        Parameter(0.0, 1, "AutoSlide"),
        Parameter(0.0, 1.0, "AmpEnvAttack"),
        Parameter(0.0, 1.0, "FiltEnvAttack"),
        Parameter(0.0, 1.0, "DriveGain"),
    ],
]

potctrl = MappedPotController(myconfig, mode=MappedPotController.MODE_RELATIVE)
# this loads a "patch" 
potctrl.load_preset(0, [2345, 0.5,  1.5, 0.5,   0.2, 0.0,  0.0, 0.0])
potctrl.load_preset(1, seqs[0][0] )

tbsynth.drive = 1.0
tbsynth.delay_time = 0.33

sequencer = TBishSequencer(tbsynth, seqs=seqs)
sequencer.bpm = bpm
sequencer.steps_per_beat = steps_per_beat

last_encoder_pos = encoder.position

tb_disp = TBishUI(display, 8)
tb_disp.update_param_pairs(*potctrl.get_display_data(0), *potctrl.get_display_data(1))
tb_disp.update_seq(seqs, sequencer.seq_num)
tb_disp.update_transpose(sequencer.transpose)

def show_step(i, steps_per_beat, seq_len):
    leds[16 + i] = 0x333333   # FIXME
    if i % steps_per_beat == 0:
        leds[Pads.LED_PLAY] = 0x333333 
    tb_disp.show_beat(i, steps_per_beat, seq_len)

sequencer.on_step_callback = show_step
sequencer.stop()

print("="*80)
print("tbish synth! press encoder button to play/pause")
print("="*80)
print("secs_per_step:%.3f" % sequencer._secs_per_step)
print("mem_free:", gc.mem_free())

#_pot_indices = tuple(range(8))  # cache the range
dim_by = const(3)
transpose = 0
transpose_oct = 0

bpm_pad_held = False  # bpm button held (twist encoder to change BPM)
spb_pad_held = False  # steps per beat button held  (encoder to change SPB)

#disp_mode = 2  # knobs: 2ndary parameters  (not yet implemented)
#disp_mode = 1  # knbos: note edit
disp_mode = 0   # knobs: synth params

tb_disp.show_mode(disp_mode)
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

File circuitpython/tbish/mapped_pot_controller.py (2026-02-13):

# SPDX-FileCopyrightText: Copyright (c) 2025 Tod Kurt
# SPDX-License-Identifier: MIT
"""
`mapped_pot_controller.py`
================================================================================

`Parameter` is a configuration for a single controlled value.

`MappedPotController` maps those parameters to knobs and back again.

10 Feb 2026 - @todbot / Tod Kurt
"""

import array

class Parameter:
    """
    Configuration for a single control parameter.

    Maps 16-bit hardware integers (0-65535) to a defined real-world range
    and handles UI formatting and callbacks.
    
    :param min_val: Lower bound of range
    :param max_val: Upper bound of range
    :param label: Display name (e.g. "Cutoff")
    :param decimals: Float precision
    :param options: List of discrete strings for option-style controls
    :param callback: Function called on change
    """
    def __init__(self, min_val, max_val, label="", decimals=2, options=None, callback=None):
        self.min = min_val
        self.max = max_val
        self.label = label
        self.decimals = decimals
        self.options = options
        self.callback = callback
        self.is_int = isinstance(min_val, int) and isinstance(max_val, int)
        self.slope = (max_val - min_val) / 65535

    def map_value(self, raw_int):
        """Converts 0-65535 to real-world range."""
        val = (raw_int * self.slope) + self.min
        return int(val + 0.5) if self.is_int else val

    def unmap_value(self, real_val):
        """Converts real-world value back to 0-65535."""
        if self.max == self.min: return 0
        raw = (real_val - self.min) / self.slope
        return int(max(0, min(65535, raw)))

    def format_value(self, raw_int):
        """Formats the value for a UI display."""
        val = self.map_value(raw_int)
        if self.options:
            return self.options[val]
        return str(val) if self.is_int else f"{val:.{self.decimals}f}"


class MappedPotController:
    """
    Logic engine for multi-bank potentiometer control mapped to Paramter values.

    Handles noise filtering (hysteresis) and provides two modes for 
    switching between virtual banks without parameter jumps.

    Constants:
        MODE_TAKEOVER (0): Value only changes once physical pot 'catches' 
            the current digital value.
        MODE_RELATIVE (1): Value changes proportionally to physical movement, 
            eliminating jumps immediately.

    :param all_configs: a list of lists of Parameters [[Param, Param...], [Bank1...]].
    :param mode: Sets interaction logic (MODE_RELATIVE or MODE_TAKEOVER).
    :param window: Hysteresis window under which changes are ignored.
    """
    
    MODE_TAKEOVER = 0
    MODE_RELATIVE = 1

    def __init__(self, all_configs, mode=1, window=800):
        self.configs = all_configs
        self.num_banks = len(all_configs)
        self.num_pots = len(all_configs[0])
        self.mode = mode
        self.window = window

        # State storage
        self.banks = [[0] * self.num_pots for _ in range(self.num_banks)]
        self.values = [0.0] * self.num_pots 
        self.current_bank = 0

        # Use array.array for hardware tracking. 
        # These are pre-allocated contiguous memory blocks that don't create new objects.
        # 'H' is unsigned short (16-bit)
        self.last_raw = array.array('H', [0] * self.num_pots)
        self.last_reported = array.array('H', [0] * self.num_pots)
        self.active_flags = [False] * self.num_pots
        
        # Pre-calculate the denominator for normalization
        self._norm_denom = 65535 - (window << 1)

    def load_preset(self, bank_idx, real_values):
        """
        Loads values into a bank. Triggers callbacks for affected parameters.
        :param bank_idx: The index of the parameter bank to set.
        :param curr_potvals: A list of real values for those parameters.
        """
        for i, val in enumerate(real_values):
            cfg = self.configs[bank_idx][i]
            raw_int = cfg.unmap_value(val)
            self.banks[bank_idx][i] = raw_int
            
            if cfg.callback:
                cfg.callback(val)

            if bank_idx == self.current_bank:
                self.active_flags[i] = False
                self.last_reported[i] = raw_int
                self.values[i] = val

    def get_display_data(self, pot_idx):
        cfg = self.configs[self.current_bank][pot_idx]
        raw = self.banks[self.current_bank][pot_idx]
        return cfg.label, cfg.format_value(raw)

    def switch_bank(self, bank_idx, curr_potvals):
        """
        Switches the active bank and synchronizes hardware history.
        Does not trigger callbacks for non-active banks.
        :param bank_idx: The index of the bank to switch to.
        :param curr_potvals: The current raw 16-bit readings from the pots.
        """
        self.current_bank = bank_idx
        for i in range(self.num_pots):
            self.active_flags[i] = False
            self.last_raw[i] = curr_potvals[i]
            raw_in_bank = self.banks[bank_idx][i]
            self.last_reported[i] = raw_in_bank
            self.values[i] = self.configs[bank_idx][i].map_value(raw_in_bank)            
                
    def update(self, curr_potvals):
        """
        Processes new hardware readings and updates bank data.
        Will trigger Parameter callbacks for changed pots.
        :param curr_potvals: List of current raw 16-bit readings.
        :return: A bitmask where each bit represents a pot that changed.
        """
        changed_mask = 0
        bank = self.banks[self.current_bank]
        
        # Local cache of constants to avoid 'self' lookups in the loop
        win = self.window
        denom = self._norm_denom
        mode_rel = self.MODE_RELATIVE

        for i in range(self.num_pots):
            raw = curr_potvals[i]
            
            # Hysteresis check
            if abs(raw - self.last_raw[i]) < win:
                continue
            
            # Optimization 3: Fixed-Point Normalization (No floats)
            if raw <= win: 
                adj = 0
            elif raw >= (65535 - win): 
                adj = 65535
            else:
                # Integer math: (numerator * 65535) // denominator
                adj = ((raw - win) * 65535) // denom
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

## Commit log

2025-06-22 finally check in sch and brd, rename to synthiota from pico_touchytouchy_synth
    [synthiota1.kicad_pcb, synthiota1.kicad_sch]
2025-06-27 pcb cleanup
    [synthiota1.kicad_pcb]
2025-06-27 pcb tweaks
    [synthiota1.kicad_pcb]
2025-06-27 lcsc part nums for everything because jlc sucks now, pcb cleanup
    [synthiota1.kicad_pcb, synthiota1.kicad_sch]
2025-06-27 added up/dn buttons! and more pcb tweaks
    [synthiota1.kicad_pcb, synthiota1.kicad_sch]
2025-07-09 rotary encoder instead
    [synthiota1.kicad_pcb, synthiota1.kicad_sch]
2025-07-09 moved pico numbers to back haha
    [synthiota1.kicad_pcb]
2025-07-09 as submitted to jlcpcb fab
    [synthiota1.kicad_pcb]
2025-07-17 remove unused 3d models from footprints
    [synthiota1.kicad_pcb]
2025-11-19 assembly directions start
    [synthiota1.kicad_pcb]
2025-11-19 add enclosure
    [synthiota_proto_case_bot.stl, synthiota_proto_case_top.stl]
2025-12-15 fix spi oled link
2025-12-18 add requirements.txt for circuitpython examples
2026-02-05 minor fixes for fun
    [code.py, tbish_synth.py]
2026-02-12 fix mapped_pot_controller options and reduce spurious update events
    [mapped_pot_controller.py]
2026-02-12 tbish: finally doing something with LEDs
2026-02-13 synth_setup_synthiota: added simple integer pot smoothing, changed tiny button MPR121 sensitivity to be less twitchy
    [synth_setup_synthiota.py]
2026-02-13 tbish synth: fix amp decay
    [tbish_synth.py]
2026-02-14 tbish: can edit steps, sequences now have separate slide track
2026-02-14 tbish: oops broke accent, fixed
    [code.py, tbish_sequencer.py, tbish_synth.py]
2026-02-15 tbish: now change bpm and steps_per_beat by holding pad and turning encoder
2026-07-04 some pcb layout for leds
2026-09-14 fix hwtest2 (M16), add hwtest3 (mozzi)
    [hwtest2.ino, hwtest3.ino]
2026-10-07 tbish2, using synthtools. and fix up encoder handling for being backwards
    [code.py, tbish2_ui.py]
2026-10-09 tbish2: add two LP filters on final output to tame a little of the aliasing
2026-10-27 start towards arduino wavesynth
2026-10-28 more arduino/wavesynth
2026-11-01 update circuitpython/readme
2026-11-01 drop sample rate of dronesynth_wt to 32k
